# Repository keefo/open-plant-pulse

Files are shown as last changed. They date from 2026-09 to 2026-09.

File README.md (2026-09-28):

# Open Plant Pulse

Open Plant Pulse is a local-first plant monitoring system with two products:

- A battery-powered **sensor node** reads a seven-parameter NPKPHCTH-S RS485 soil
  probe and an SHT45 ambient sensor, then broadcasts each wake-cycle sample using
  BTHome v2 over BLE.
- An always-on **desktop hub** subscribes to nearby BTHome sensors on macOS or
  Linux, stores history, derives plant-state insights, and hosts a local HTTP web
  application for household management and monitoring.

The sensor can still be discovered directly by Home Assistant. The hub is for
users who want durable local history, analysis, native notifications, APIs, and
multi-system forwarding without putting those responsibilities on the battery
device.

> [!IMPORTANT]
> This repository is in the prototype stage. SQLite persistence, internal
> browser endpoints, dashboard, and BTHome encode/decode logic are tested, but
> continuous BLE collection, target hardware, predictions, and packaging have
> not been validated end to end.

## What it looks like

Small previews; click one for the whole page.

<table>
<tr>
<td width="33%" valign="top">
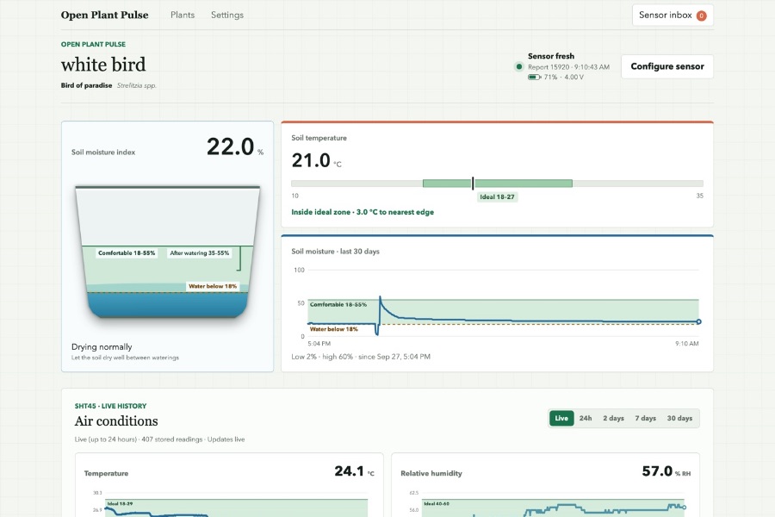
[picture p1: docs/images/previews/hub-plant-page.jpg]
A plant's page on the hub

<br><b>A plant's page</b>
<br><sub>Readings against the plant's own profile, air history, the conclusions
drawn from them, a year of care, its lights, and the log of what happened.</sub>
</td>
<td width="33%" valign="top">
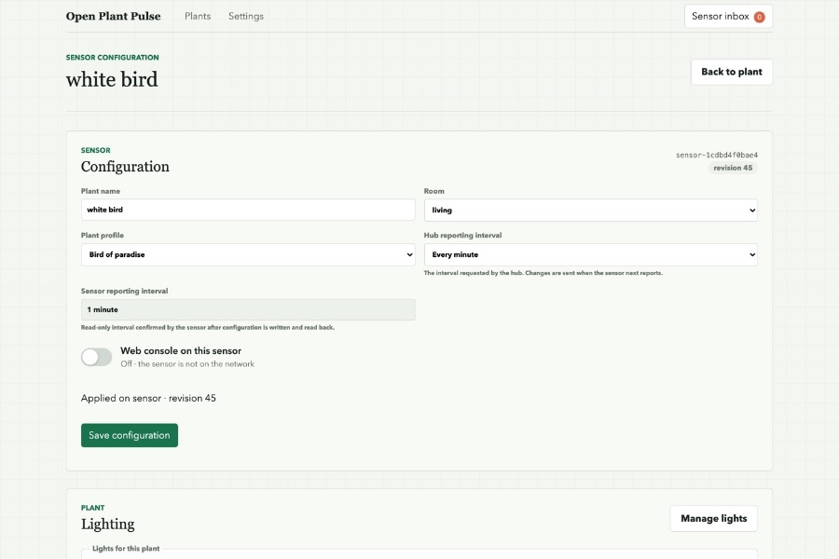
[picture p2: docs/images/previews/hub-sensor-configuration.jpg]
A sensor's configuration page

<br><b>A sensor's configuration</b>
<br><sub>What is the device's rather than the plant's: what the hub asks of it,
the lights it drives, and the firmware it runs — installed from here, over the
air.</sub>
</td>
<td width="33%" valign="top">
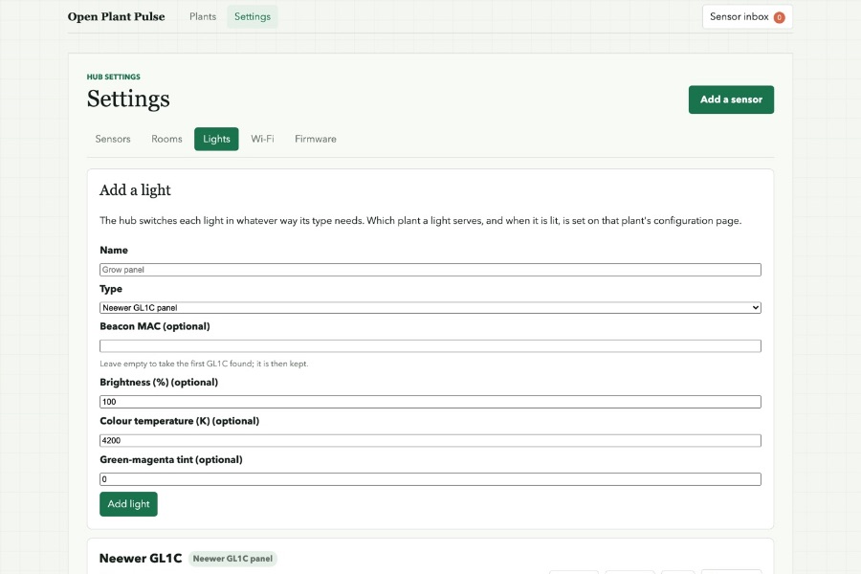
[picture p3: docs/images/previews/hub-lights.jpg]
Managing grow lights

<br><b>Grow lights</b>
<br><sub>Each light is added once and given to a plant, which owns the daily
window they follow.</sub>
</td>
</tr>
</table>

A sensor also serves its own console on the household network, for looking at
the device rather than the plant.

<table>
<tr>
<td width="50%" valign="top">
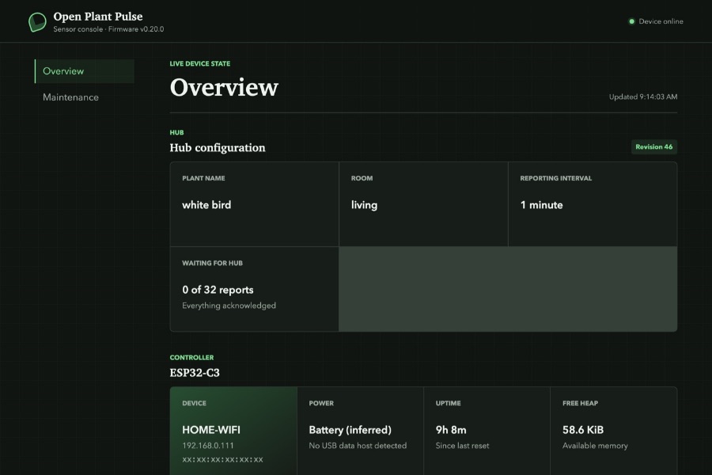
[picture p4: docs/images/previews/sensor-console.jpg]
The sensor's own console

<br><b>The sensor's console</b>
<br><sub>What each part of the device reads, what the battery is doing, and the
firmware log as it happens.</sub>
</td>
<td width="50%" valign="top">
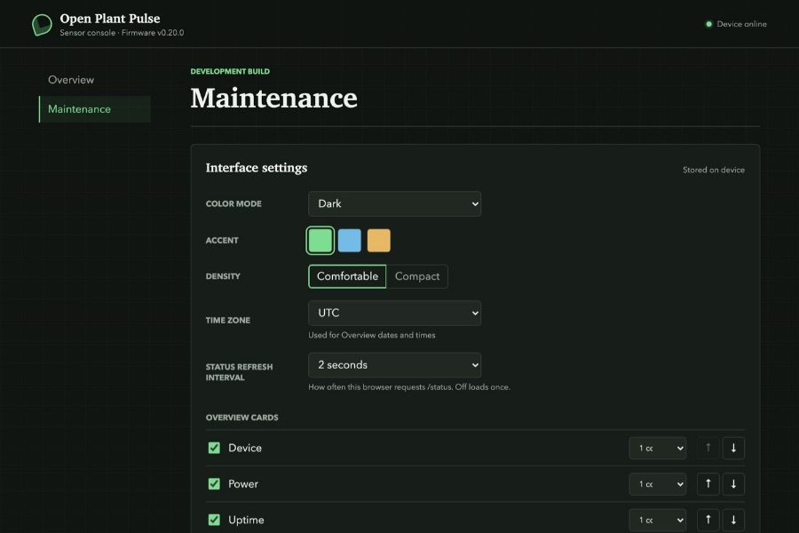
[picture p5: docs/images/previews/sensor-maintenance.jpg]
The sensor's maintenance page

<br><b>Maintenance</b>
<br><sub>Interface settings kept on the device, a forced report, and a restart.</sub>
</td>
</tr>
</table>

The Wi-Fi name and hardware addresses in these screenshots are replaced; the
readings are a real sensor's.

## Repository layout

```text
open-plant-pulse/
├── sensor/                  Battery sensor product
│   ├── firmware/            ESP-IDF application and components
│   ├── hardware/            Assembly BOM, wiring, and future CAD/PCB assets
│   └── tests/               Host-side sensor protocol tests
├── hub/                     Installable Python desktop/server product
│   ├── src/                 Domain and adapter packages
│   └── tests/               Hub unit and integration tests
├── protocol/                Versioned sensor-to-hub contract and fixtures
├── deploy/                  macOS LaunchAgent; systemd and packaging to come
├── docs/                    System architecture, setup, roadmap, and proposals
├── examples/                Downstream integration examples
└── scripts/                 Repository-wide validation commands
```

Product code stays inside `sensor/` or `hub/`. Data exchanged between them is
specified in `protocol/`; neither product may privately redefine that contract.

## Run the hub

Start the local hub from the repository root:

```sh
PYTHONPATH=hub/src python3 -m open_plant_pulse_hub
```

Open <http://localhost/>. The hub listens for BTHome advertisements from
sensors in range; add one from Settings, and its soil, air, and nutrient readings
appear as they arrive.

## Start here

1. Read [the system architecture](docs/architecture.md) and
   [shared protocol](protocol/README.md).
2. For hardware work, use the [sensor guide](sensor/hardware/README.md),
   [BOM](sensor/hardware/BOM.md), [enclosure workspace](sensor/hardware/enclosure/README.md),
   and [bring-up checklist](docs/bring-up.md).
3. To start with a XIAO ESP32-C3 and SHT45 only, follow the
   [first sensor-node guide](docs/sht45-first-node.md). For broader embedded
   development, use [the sensor firmware guide](docs/firmware.md).
4. For desktop development, follow [the hub guide](docs/hub.md).
5. Choose a direct or hub-mediated Home Assistant path in
   [the integration guide](docs/home-assistant.md).

## Repository checks

These checks require only a C compiler and Python 3.9 or newer:

```sh
sh scripts/check.sh
```

## Sensor firmware

Use the repository scripts for ESP32-C3 work. They locate and activate ESP-IDF,
select the correct project directory, and keep the commands reproducible:

```sh
sensor/firmware/build.sh
sensor/firmware/flush.sh
```

`flush.sh` builds, auto-detects a single USB serial device, flashes it, and opens
the monitor. Exit the monitor with `Ctrl-]`. Use `--no-monitor` for flash only or
`--port /dev/DEVICE` when multiple serial devices are connected. Future tooling
and automation should call these scripts instead of duplicating raw `idf.py`
commands.

## Current status

| Area | Status |
| --- | --- |
| Sensor Modbus parser and BTHome encoder | Host tested |
| Simulated sensor to hub to web dashboard | Runnable and integration tested |
| Hub SQLite persistence and current HTTP dashboard | Runnable and integration tested |
| Hub BLE subscriber and multi-sensor storage | Implemented and replay tested; macOS physical reception verified, Linux pending |
| Direct BTHome Home Assistant path | Encoder/decoder host tested; hardware pending |
| ESP-IDF target application | Firmware 0.5.0 adds a tracked manual report with exact Hub acknowledgment to the always-awake bench UI; build/flash/live results are recorded in the worklog, while production sleep/power/soak validation remains pending |
| Grow light control (Neewer GL1C, Wemo-switched light) | Running on the hub: both lights confirmed on and off, schedule edge and restart checked; GL1C colour and off edge unverified |
| Multi-plant management UI | Fleet-to-detail navigation, enrollment, per-sensor configuration delivery state, rename/delete, and sensor-specific freshness are host tested |
| Public HTTP API, sensor Wi-Fi/HTTP, MQTT, notifications | Lower priority |
| Electrical design and enclosure | Needs prototype validation |

See [the roadmap](docs/roadmap.md) for acceptance criteria. The original Chinese
[sensor](docs/proposals/sensor-node.zh-CN.md) and
[hub](docs/proposals/desktop-hub.zh-CN.md) brainstorms are retained as proposals,
not specifications. The project is licensed under the [MIT License](LICENSE).

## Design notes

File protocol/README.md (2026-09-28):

# Sensor-to-hub protocol

This directory owns the contract between the battery sensor and desktop hub.
Neither product may change its payload independently.

## BTHome contract version 3

Contract v3 is the only contract. Earlier contracts are not decoded; a sensor
still sending one is reflashed rather than accommodated. It remains unencrypted
BTHome v2 service data under UUID `0xFCD2`; `3` is the Open Plant Pulse
contract version, not a BTHome format version. Every packet begins with
device-info byte `0x40` (regular interval, unencrypted) and lists its objects in
ascending object-ID order.

One **report** is one set of measurements taken together. It always travels as
two packets that share a report ID, advertised alternately: **packet 1** with
the soil and air measurements and the acquisition time, and **packet 2** with
the battery, pH and N/P/K. Neither is optional; a report is complete only when
the hub holds both. A third shape, the **beacon**, carries no report at all.

### Packet 1: soil, air and time

Sizes include the one-byte object ID.

| Wire order | Object | ID | Encoding | Group | Size |
| --- | --- | --- | --- | --- | --- |
| 0 | Device info | `0x40` | first byte, not an object | Required | 1 |
| 1 | Soil temperature | `0x02` | signed 16-bit; factor 0.01 degrees C | Soil | 3 |
| 2 | Air relative humidity | `0x2E` | unsigned 8-bit; 1 % | Air | 2 |
| 3 | Soil moisture | `0x2F` | unsigned 8-bit; 1 % | Soil | 2 |
| 4 | Report ID (`count`) | `0x3E` | unsigned 32-bit | Required | 5 |
| 5 | Air temperature | `0x45` | signed 16-bit; factor 0.1 degrees C | Air | 3 |
| 6 | Acquisition timestamp | `0x50` | unsigned 32-bit Unix seconds | Optional | 5 |
| 7 | Conductivity | `0x56` | unsigned 16-bit; 1 microS/cm | Soil | 3 |

All multi-byte values are little-endian. A group is complete or absent: soil is
`0x02`, `0x2F` and `0x56`; air is `0x2E` and `0x45`. At least one group is
present. A failed source omits its whole group, and the receiver stores null
measurements with an unavailable source status rather than copying earlier
values. Percentages are rounded to the nearest whole point, `0` to `100`. With
everything present the service data after the UUID is 24 bytes, which with the
Flags element and service-data header fills the 31-byte legacy advertisement;
the local name travels in the scan response.

### Packet 2: battery, pH and N/P/K

| Wire order | Object | ID | Encoding | Group | Size |
| --- | --- | --- | --- | --- | --- |
| 0 | Device info | `0x40` | first byte, not an object | Required | 1 |
| 1 | Battery | `0x01` | unsigned 8-bit; 1 % | Battery | 2 |
| 2 | Battery voltage | `0x0C` | unsigned 16-bit; factor 0.001 V | Battery | 3 |
| 3 | Battery charging | `0x16` | unsigned 8-bit; `0` not charging, `1` charging | Battery | 2 |
| 4 | Report ID (`count`) | `0x3E` | unsigned 32-bit | Required | 5 |
| 5 | Soil extras (`raw`) | `0x54` | length byte `0x08`, then the layout below | Soil extras | 10 |

Battery is `0x01`, `0x0C` and `0x16` together or none of them. Charging means
current into the pack above the monitor's idle threshold (15 mA), from whatever
source: the IP2312 or the XIAO's own USB charger. Every report sends packet 2,
even when it carries only the report ID: that is how the hub knows a report is
complete, rather than guessing whether a second packet was lost or never
existed. At most 23 bytes.

BTHome defines no pH or nutrient objects, so they travel in one raw object that
only the hub decodes (Home Assistant shows battery natively and ignores it):

| Offset | Size | Field |
| --- | --- | --- |
| 0 | 1 | Layout version, `1` |
| 1 | 1 | pH, factor 0.1 (`0`-`140`) |
| 2 | 2 | Nitrogen, mg/kg |
| 4 | 2 | Phosphorus, mg/kg |
| 6 | 2 | Potassium, mg/kg |

A packet is packet 1 if it carries any of `0x02`, `0x2E`, `0x2F`, `0x45`, `0x50`
or `0x56`, and packet 2 otherwise: `0x01`, `0x0C`, `0x16` and `0x54`, or the
report ID alone. A packet mixing the two sets, missing the report ID, or carrying any
other object is malformed.

### Beacon

The single byte `0x40`, with no objects. A sensor sends it when it has no
report (for example, no sensor is available yet), so that it can still be found
and adopted. A beacon is presence only: nothing is stored from it.

### Byte budget and worked example

A legacy BLE advertisement carries at most 31 bytes. Every contract-v3 packet
spends them the same way:

```text
┌──────────────────────────── 31 bytes ────────────────────────────┐
│ 02 01 06 │ LL 16 D2 FC │ BTHome payload: up to 24 bytes           │
│  Flags   │ service-data│ 40, then objects                         │
│  3 bytes │ header, 4 B │                                          │
└──────────────────────────────────────────────────────────────────┘
```

- **Flags** (length, type `0x01`, value `0x06`) make the sensor discoverable.
- **Service-data header**: length `LL`, AD type `0x16` (service data, 16-bit
  UUID) and the BTHome UUID `0xFCD2`, little-endian `D2 FC`.
- **Payload**: 31 − 3 − 4 = **24 bytes**. It starts with the device-info byte
  `0x40`; each object is its one-byte ID followed by its little-endian value,
  in ascending ID order.

The device-info byte is a bit field defined by BTHome. `0x40` is `0100 0000`:

| Bits | Field | Value in `0x40` | Meaning |
| --- | --- | --- | --- |
| 0 | Encryption | `0` | Not encrypted |
| 1 | Reserved | `0` | |
| 2 | Trigger-based device | `0` | Advertises at regular intervals, not only on events |
| 3-4 | Reserved | `00` | |
| 5-7 | BTHome version | `010` = 2 | BTHome v2 |

Every packet 1, packet 2 and beacon begins with exactly `0x40`; any other value
is malformed. An encrypted contract would set bit 0 (`0x41`) and change the
rest of the payload, and needs a new contract.

The local name `sensor-<DEVICE_ID>` is not in this budget: it travels in the
scan response.

**Packet 1**, fixture `packet1`, 24 of 24 bytes:
`40 02 2e09 2e 2c 2f 64 3e d2040000 45 1001 50 0037b86a 56 2900`

| Bytes | ID | Value | Meaning | Size |
| --- | --- | --- | --- | --- |
| `40` | | `0100 0000` | Device info: BTHome v2, unencrypted, regular interval | 1 |
| `02 2e09` | `0x02` | 0x092E = 2350 x 0.01 | Soil temperature **23.50 C** | 3 |
| `2e 2c` | `0x2E` | 0x2C = 44 | Air humidity **44 %** | 2 |
| `2f 64` | `0x2F` | 0x64 = 100 | Soil moisture **100 %** | 2 |
| `3e d2040000` | `0x3E` | 1234 | **Report ID** | 5 |
| `45 1001` | `0x45` | 0x0110 = 272 x 0.1 | Air temperature **27.2 C** | 3 |
| `50 0037b86a` | `0x50` | 1790457600 | Timestamp **2026-09-26T21:20:00Z** | 5 |
| `56 2900` | `0x56` | 0x29 = 41 | Conductivity **41 uS/cm** | 3 |
| | | | **Total** | **24** |

**Packet 2**, fixture `packet2`, 23 of 24 bytes:
`40 01 60 0c 4010 16 00 3e d2040000 54 08 01 44 0100 0200 0700`

| Bytes | ID | Value | Meaning | Size |
| --- | --- | --- | --- | --- |
| `40` | | `0100 0000` | Device info: BTHome v2, unencrypted, regular interval | 1 |
| `01 60` | `0x01` | 0x60 = 96 | Battery **96 %** | 2 |
| `0c 4010` | `0x0C` | 0x1040 = 4160 x 0.001 | Battery **4.160 V** | 3 |
| `16 00` | `0x16` | 0 | Charging: **no** | 2 |
| `3e d2040000` | `0x3E` | 1234 | **Same report ID**, joining it to packet 1 | 5 |
| `54 08 …` | `0x54` | raw, length 8 | Soil extras, below | 10 |
| | | | **Total** | **23** |

The soil extras, `01 44 0100 0200 0700`:

| Bytes | Value | Meaning | Size |
| --- | --- | --- | --- |
| `01` | 1 | Layout version | 1 |
| `44` | 0x44 = 68 x 0.1 | pH **6.8** | 1 |
| `0100` | 1 | Nitrogen **1 mg/kg** | 2 |
| `0200` | 2 | Phosphorus **2 mg/kg** | 2 |
| `0700` | 7 | Potassium **7 mg/kg** | 2 |

**Room left** with every object present:

| Packet | Used | Free |
| --- | --- | --- |
| Packet 1 | 24 | 0 |
| Packet 2 | 23 | 1 |
| Packet 2, report ID only (`40 3e d3040000`) | 6 | 18 |
| Beacon (`40`) | 1 | 23 |

A new field must fit in the free bytes of the packet it belongs to, including
its one-byte object ID, or replace something; a third packet would spread each
report's airtime more thinly. The sensor advertises a report's two packets
alternately, swapping every 500 ms, every 50 ms while always awake and every
250 ms in the production cycle. The bulk drain does not use advertisements: its
pages travel over a connection and may be up to 512 bytes.

### Identity, report IDs and deduplication

The sensor advertises the complete local name `sensor-<DEVICE_ID>`, where
`DEVICE_ID` is its immutable 48-bit hardware device ID as 12 lowercase
hexadecimal digits. The name is the sensor's identity and stays stable across
resets, hub replacement and platform address changes. Platform-observed
addresses are diagnostics only. The identity is visible and spoofable because
the contract is unauthenticated.

Report IDs start at `1`, increase with every new report, never repeat and never
wrap. Gaps are allowed: the sensor reserves IDs in blocks in flash so that it
writes flash once per block rather than once per report, and after a restart it
continues from the end of the reserved block. `0` is never used.

The hub's key for a report is `(sensor identity, report ID)`. Packets 1 and 2
of one report may arrive in either order and are joined into one reading; a
reading appears once packet 1 is stored, with packet 2's values attached
whenever they arrive. A report is complete when
both are stored, and only a complete report is shown as a sensor's latest
reading, so one whose second packet is still coming does not blank its values. Receiving a packet whose
content matches what is already stored for its key is a duplicate and stores
nothing; this is how repeated advertising of one report is absorbed. The same
key with different content for the same packet kind is a conflict: it is
logged and not stored. Erasing the sensor's flash restarts its report IDs, so
such a sensor must be removed from the hub and adopted again.

### Security

Contract v3 is unencrypted: measurements, identity and presence are observable
and not authenticated. Encryption requires a new contract with BTHome bind-key
provisioning, protected key storage, replacement and recovery, and Home
Assistant interoperability. Keys must never appear in fixtures or logs.

### Fixtures

[`fixtures/bthome-v3.json`](fixtures/bthome-v3.json) records a known packet 1 and
packet 2 pair and a beacon. The sensor's encoder tests and the hub's
decoder tests both check against it.

### Acquisition timestamp

Use the standard BTHome timestamp object `0x50`, not a text datetime or a custom
object. Its value is a POSIX/Unix timestamp: whole seconds since
`1970-01-01T00:00:00Z`, encoded as an unsigned 32-bit little-endian integer and
interpreted in UTC. It carries no timezone offset and does not represent leap
seconds. For example, `2026-09-13T12:00:00Z` is Unix value `1789300800` and is
encoded as `50 40 90 A6 6A` including the object ID.

The Hub converts a present `0x50` value to canonical RFC 3339 UTC text in the form
`YYYY-MM-DDTHH:MM:SSZ` for its API and storage. That value becomes `observed_at`.
The separately recorded `received_at` is always the Hub's reception time and must
not be substituted for acquisition time.

The sensor emits `0x50` only after its clock has been synchronized and passes the
firmware plausibility window from `2024-01-01T00:00:00Z` through the end of 2099.
Deep sleep may retain that clock state; loss of power makes time unknown until a
new trusted synchronization succeeds. A sample acquired while time is unknown
omits `0x50` permanently, including on retries after a later synchronization. It
must not encode zero, estimate from reception time, or rewrite the immutable queued
report. The Hub stores `observed_at` as null for such a report while retaining
`received_at`; this requires a v3 storage migration because the v2 column is not
nullable.

### Durable delivery and acknowledgement

A report is kept until the hub confirms it has stored it. This replaced
one-way delivery, in which a report the hub missed was lost.

**Sensor.** Once the sensor belongs to a hub, each new report is written to a
queue in flash before it is first advertised, and stays there until
acknowledged. The sensor advertises its newest report, both packets
alternately, from the moment it is made, so the hub sees fresh data within a
second or two whatever is still queued behind it; older ones reach the hub by
the drain below. Reports are made on a fixed schedule: an advertising window is
cut short rather than delay a report that is due. A deep-sleeping sensor retries at each
wake. When the queue is full, the sensor makes no new reports and says so on its
console, rather than overwriting an unacknowledged one. An unclaimed sensor has
no hub that could acknowledge anything, so it does not queue: it advertises its
latest report without keeping it. A release by the hub clears the queue.

**Freshness.** The hub stores the newest report straight from its
advertisement, as with any packet, and shows the highest complete report ID as
the latest, so a report backfilled later never displaces a newer one.

**Hub: bulk drain.** The drain makes delivery complete and lets the sensor free
its queue. It is not the freshness path: a connection pauses the sensor's
advertising for a moment, so the hub does not drain after every report. On
hearing a report not yet acknowledged from a sensor it owns, the hub drains
when the report IDs it holds since the last acknowledgement have a gap
(something was missed over the air), when about 30 seconds have passed since
its last drain of that sensor, or on the first such report after the hub
starts. A drain that is due waits until the report just heard is complete,
both packets stored, so the connection falls in the quiet part of the
reporting cycle rather than across a fresh report; if none completes over the
air within 10 seconds it drains anyway, and other connection work waits to ride
on the same connection. Over one connection it drains the whole queue in pages, oldest first, on the
existing read/write characteristic `7f510002-1b15-4c28-9a4a-8d0f4f505000`
(bonded, encrypted):

1. Write the drain request `20`. From then on, until the end token or the
   disconnect, a read of the characteristic returns a queue page instead of
   the device configuration.
2. Read a page. Each page holds up to eight of the oldest queued reports, each
   exactly the two packets the sensor advertises for it.
3. Store every report on the page, through the same duplicate and conflict
   rules as advertised packets.
4. Write the cumulative acknowledgement for the last report stored. The sensor
   removes every queued report up to and including it.
5. Repeat from 2 until a page is empty, then write the end token `22`.

One connection moves any backlog, so draining outpaces reporting whenever the
hub is up: at a report every five seconds, a drain every 30 seconds finds about
six, two pages.
The hub does its configuration and status work on the same connection, before
the drain request or after the end token.

**Queue page** (read, at most 512 bytes):

| Offset | Size | Field |
| --- | --- | --- |
| 0 | 1 | `0x20` |
| 1 | 1 | Report count, `0` to `8` |
| 2 | ... | That many records, oldest first |

Each record is the report ID (4 bytes, unsigned little-endian), packet 1's
length (1 byte) and bytes, then packet 2's length (1
byte) and bytes: the service data exactly as advertised, after the UUID. A page
is fixed until the queue changes, so the reads that assemble a long value see
the same bytes.

**Cumulative acknowledgement** (write, five bytes):

| Offset | Size | Field |
| --- | --- | --- |
| 0 | 1 | `0x21` |
| 1 | 4 | Report ID, unsigned little-endian |

It removes every queued report with an ID up to and including this one. It is
refused, removing nothing, when the ID is `0` or beyond the last report the
sensor has put on a page during this connection: the hub can acknowledge only
what it has read. Naming a report already removed is accepted and changes
nothing. Removal is durable before the sensor answers. A report in conflict is
never acknowledged, so the hub acknowledges only up to the report before it.

**End of drain** (write, one byte): `22`. Reads return the device configuration
again; disconnecting has the same effect.

A report forced from the sensor's console is an ordinary report: it joins the
queue, and the console shows it acknowledged when a cumulative acknowledgement
covers it.

## Change policy

- There is one contract at a time. A new contract replaces the old one in the
  sensor, the hub and the fixtures together; no compatibility is kept.
- Update sensor encoding, hub decoding, replay behavior, and tests together.
- Treat incompatible identity, deduplication, encryption, or object semantics as
  a new contract version.
- Add BTHome fields in ascending object-ID order unless a documented compatibility
  reason requires otherwise.
- Document receiver behavior before emitting an object Home Assistant or the hub
  may not understand.

## Connected-BLE device configuration version 2

BTHome advertisements remain the telemetry contract. During the same bounded
advertising window, firmware also accepts a BLE connection exposing primary service
`7f510001-1b15-4c28-9a4a-8d0f4f505000` and read/write characteristic
`7f510002-1b15-4c28-9a4a-8d0f4f505000`. After an enrolled sensor advertises, the hub
writes pending device configuration and reads the characteristic back. Only an
identical read-back marks the revision applied; failures remain pending for a later
report.

The characteristic value is a canonical binary payload:

| Offset | Size | Field |
| --- | --- | --- |
| 0 | 1 | Protocol version, currently `2` |
| 1 | 4 | Non-zero configuration revision, unsigned little-endian |
| 5 | 4 | Reporting interval in seconds, unsigned little-endian, `1`–`86400`; the hub sends no less than `30` |
| 9 | 1 | Plant-name byte length, `1`–`80` |
| 10 | 1 | Room byte length, `0`–`80` |
| 11 | variable | Plant name followed by room, UTF-8 without control characters |

Version 1 used a two-byte interval in minutes and accepted only 5 minutes through
24 hours. Version 2 is intentionally incompatible so sub-minute intervals cannot be
misinterpreted by older firmware. After migration, the hub resends enrolled sensor
configuration using version 2.

The sensor validates the entire payload before atomically storing it in NVS. It
renders plant name and room on its diagnostics dashboard and uses the interval for
future awake reports or deep-sleep timer wake-ups until another valid configuration
is applied. Plant profile, thresholds, archival state, and history stay hub-owned.

This prototype characteristic is unencrypted and unauthenticated. Nearby clients
can observe or overwrite configuration. Pairing, authorization, recovery, and
measured connection-window energy are required before production deployment.

## Connected-BLE Wi-Fi credentials version 3

The hub holds one household network for the whole house and sends it to any sensor
whose web console is switched on. The sensor stores it in NVS and joins. Readings
never depend on it: telemetry is BTHome either way, and a sensor with its console
off is fully functional.

This is a third payload on the same read/write characteristic
`7f510002-1b15-4c28-9a4a-8d0f4f505000`, distinguished by its first byte as the
other two are. It is a separate payload rather than an extension of device
configuration for two reasons: that payload already occupies 171 of the roughly
253 bytes an ATT write carries at the negotiated MTU, and Wi-Fi is optional while
plant name and interval are not.

| Offset | Size | Field |
| --- | --- | --- |
| 0 | 1 | Protocol version, `3` |
| 1 | 4 | Revision, unsigned little-endian |
| 5 | 1 | Console enabled, `0` or `1` |
| 6 | 1 | Network name length, at most 32 |
| 7 | n | Network name |
| 7+n | 1 | Password length, at most 63 |
| 8+n | m | Password |

A disabled console still carries its network, so switching it back on needs
nothing resent. A payload that claims an enabled console with no network name is
refused, as is any payload whose declared lengths do not account for exactly the
bytes received. The sensor never returns the password on a read, and it appears in
no status response, log, or serial output.

> [!IMPORTANT]
> This payload carries a household secret, so it may only be written over a
> bonded, encrypted link. The characteristic requires encryption from firmware
> 0.6.0; earlier firmware accepted reads and writes from anything in range and
> must not be given credentials.

## Development transports

BLE is the only transport. Deterministic tests replay the contract-v3 fixtures
above; there is no side channel a sensor may use instead.

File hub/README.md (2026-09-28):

# Open Plant Pulse Hub

The hub is the always-on desktop/server side of Open Plant Pulse. Its target design
subscribes to BTHome advertisements over BLE, stores local history, derives
plant-state signals, and hosts a local HTTP web application where household users
manage and monitor sensors.

## Target hosts

- macOS.
- Linux.

Both hosts run the same Python BLE, HTTP, and SQLite service. Native scanning and
physical BTHome reception have been exercised on macOS; Linux permissions remain to
be tested. LAN binding and firewall behavior apply to browser access, not sensor
ingestion. Platform service packaging belongs under the repository-level `deploy/`
tree.

## Package boundaries

```text
hub/
├── src/open_plant_pulse_hub/
│   ├── domain/       Stable telemetry and plant models
│   └── ingestion/    BTHome decode, Bleak scan, replay, and development adapters
├── tests/            Hub unit and integration tests
└── pyproject.toml    Package metadata and dependency groups
```

Adapters for Bluetooth, SQLite, household HTTP, and later MQTT, notifications,
prediction, and public APIs must depend on the domain layer, not the reverse.

## Development

Run the development hub from the repository root:

```sh
PYTHONPATH=hub/src python3 -m open_plant_pulse_hub
```

Then open the fleet at <http://localhost/>. Sensor monitoring is available at
`/sensors/<sensor-id>`, where that sensor's configuration is also managed. The hub
scans for BTHome advertisements as it runs, so a sensor in range appears under
Settings and can be added from there. Readings and care events persist in SQLite;
a short live history is restored after restart.

A second server, on port 8081, serves firmware images to sensors on the household
network; the management interface above stays on loopback. Add an image under
Settings · Firmware and install it from a sensor's configuration page. Run with
`--no-firmware-server` to keep images without serving them.

The tests use only the Python standard library:

```sh
PYTHONPATH=hub/src python3 -m unittest discover -s hub/tests
```

To prepare an isolated development environment later:

```sh
python3 -m venv .venv
. .venv/bin/activate
python3 -m pip install -e './hub[dev]'
```

## Current status

The development hub receives contract-v3 BTHome advertisements through Bleak, joins
each report's packet 1 and packet 2 into one reading keyed by report ID,
drains each enrolled sensor's delivery queue over one connection (bulk drain with
cumulative acknowledgement) so the sensor can drop what the hub has stored,
persists unique readings and bounded receive
diagnostics in migrated SQLite storage, restores a short live history after
restart, serves JSON endpoints, and renders a local dashboard. The shared replay
path tests three stable sensor identities, joining in either packet order, duplicate
and conflict handling, partial sources, readings without a sensor timestamp,
malformed isolation, and adapter recovery. The production subscriber stored physical
BTHome reports on macOS, and direct CoreBluetooth access verified the firmware's
configuration write/read-back on 2026-09-14; Linux remains unvalidated.
The household UI provides a fleet page and per-sensor detail pages. Fleet cards open
the corresponding detail page and show name, stable identifier, last report, and
state. Each detail page includes all sensor configuration, archive/replacement,
destructive deletion, and pending/applied/retrying state for plant name, room, and
reporting interval. The requested hub interval remains editable while a separate
read-only field shows the interval last confirmed from firmware and used for hub
freshness calculations.
Each sensor detail page shows battery level and voltage, with a lightning bolt over
the battery while it is charging, and soil pH, nitrogen,
phosphorus, and potassium when the sensor reports them, and includes a temporary,
newest-first raw BTHome report log for debugging, capped at the latest 50 reports,
listing each packet's report ID and kind.
The sensor inbox retains deliberate enrollment.
These flows and the connected-BLE codec/read-back synchronizer are integration-tested;
single-sensor physical configuration delivery is verified, while production-hub
delivery scheduling, multi-sensor radio behavior, and responsive-browser validation
remain pending. A stable public HTTP API, sensor
Wi-Fi/HTTP, MQTT, predictive analytics, backups, and service installation are lower
priority.

The canonical current and target design is in [`../docs/hub.md`](../docs/hub.md).

## Plant profile catalog

Plant profiles are JSON data under
`src/open_plant_pulse_hub/data/plant_profiles/`. Add one file following the
directory README and schema; the generic loader discovers and validates it
without any Python registry change.

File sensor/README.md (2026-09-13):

# Open Plant Pulse sensor

The sensor is the battery-powered product installed at the plant. It reads a
ComWinTop NPKPHCTH-S soil probe over Modbus RTU and an SHT45 air sensor over I2C,
encodes implemented measurements as BTHome v2, briefly advertises over BLE, and
returns to deep sleep. The probe supports N/P/K, pH, conductivity, soil
temperature, and soil moisture; firmware currently implements only the latter
three.

```text
sensor/
├── firmware/          ESP-IDF main component and reusable protocol components
├── hardware/          Top-level assembly BOM and hardware guidance
├── tests/             Dependency-free C protocol tests
├── CMakeLists.txt      ESP-IDF project entry point
└── sdkconfig.defaults Portable target defaults
```

Read the [firmware guide](../docs/firmware.md),
[hardware guide](hardware/README.md), and
[enclosure workspace](hardware/enclosure/README.md), and
[shared radio contract](../protocol/README.md) before making changes.

From the repository root, use the canonical scripts:

```sh
sensor/firmware/build.sh
sensor/firmware/flush.sh
```

The flash script builds first, auto-detects a single USB serial port, flashes,
and opens the monitor. Run `sensor/firmware/flush.sh --help` for explicit port
and flash-only options. Reuse these scripts in development and automation rather
than assembling separate `idf.py` command sequences.

Run sensor protocol tests from the repository root:

```sh
sh scripts/test-sensor.sh
```

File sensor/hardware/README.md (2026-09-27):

# Hardware

The procurement source of truth is the [bill of materials](BOM.md) and its
machine-readable [`bom.csv`](bom.csv). The table below summarizes the prototype
architecture and must not be used as a substitute for exact orderable parts.

## Reference prototype

| Function | Reference part | Required verification |
| --- | --- | --- |
| Controller | Seeed Studio XIAO ESP32-C3 | Board revision and pin map |
| RS485/power | XIAO-format RS485 expansion board | Input range, 12 V capacity, enable pin, idle current |
| Probe | ComWinTop NPKPHCTH-S | Product revision, wire colors, voltage, register map, scaling |
| Air sensor | Sensirion SHT45 or SHT45 breakout | Exact MPN/module, supply voltage, mounting, idle current |
| Battery | Protected 3.7 V 18650 cell and holder | Protection, polarity, peak-current capability |
| Cable entry | PG7 gland sized for probe cable | Grip and ingress protection |
| Enclosure | Printed PETG/ASA prototype | Clearances, ventilation, strain relief |

Part numbers are not interchangeable merely because they share an enclosure or
product-family name. Save each purchased part's manual and revision under a
release or issue before freezing the design.

## Pin map

This is the assembled prototype's wiring: a XIAO ESP32-C3 on the XIAO RS485
board, with the SHT45 and INA219 sharing one I2C bus.

| Signal | XIAO label | ESP32-C3 GPIO | Connected to |
| --- | --- | --- | --- |
| RS485 UART TX | D4 | GPIO6 | RS485 board transceiver input |
| RS485 UART RX | D5 | GPIO7 | RS485 board transceiver output |
| RS485 driver enable | D2 | GPIO4 | RS485 board DE |
| I2C SDA | D1 | GPIO3 | SHT45 and INA219 SDA |
| I2C SCL | D3 | GPIO5 | SHT45 and INA219 SCL |
| Probe power | D10 | GPIO10 | AO3400 gate: high powers the MT3608 and probe |

The RS485 board occupies D4/D5, so no I2C device may use them: the
transceiver's receiver output actively drives D5, which corrupts I2C. The
ESP32-C3 has one I2C controller, so every I2C device belongs on D1/D3. The
INA219 at `0x40` and the SHT45 at `0x44` do not collide; do not bridge the
INA219's A1 pad, which would move it to `0x44`.

The probe is powered from an MT3608 boost converter set to 12.4 V on the system
node, switched by an AO3400 N-MOSFET in the MT3608's ground (see
[probe power switch](#probe-power-switch)).

## Power path

The assembled prototype runs from two 18650 cells in parallel (still one 3.7 V
cell electrically) and charges them through an IP2312 USB-C charger module.

| From | To | Notes |
| --- | --- | --- |
| USB-C charger | IP2312 USB-C input | The only charging input |
| IP2312 BAT+ | System node | Short, thick wires (20-22 AWG) |
| System node | INA219 VIN+ | |
| INA219 VIN- | Battery pack P+ | The shunt sits in series with the pack |
| System node | MT3608 IN+ | Boost converter for the probe |
| System node | XIAO BAT+ pad | Powers the controller |
| MT3608 OUT+ (12.4 V) | Probe brown | Set the voltage before connecting the probe |
| MT3608 OUT- | Probe black | Same net as MT3608 IN-, switched by the AO3400 |
| MT3608 IN- | AO3400 drain (pin 3) | The MT3608's only path to ground |
| AO3400 source (pin 2) | System ground | |
| XIAO D10 (GPIO10) | AO3400 gate (pin 1) | 10-100 kOhm gate-to-source pull-down |

IP2312 BAT-, pack P- and the XIAO BAT- pad share one ground. MT3608 IN- and
OUT- reach it only through the AO3400. The
INA219 and SHT45 take ground from the XIAO GND pin, which is the same net.

Because the INA219's VIN+ is on the system node and VIN- on the pack, its
current is **positive while charging** and negative while the node runs from
the battery. The firmware reads it as a battery monitor; see
[firmware development](../../docs/firmware.md#battery-monitor). Its shunt value
and the cells' capacity are build settings that must match the parts.

### Probe power switch

The MT3608's own enable pin cannot switch the probe off: a disabled boost
converter still passes the battery voltage, less a diode drop, through its
inductor and diode to the output, leaving the probe half powered. None of the
other modules can switch a load either, and the RS485 board's 12V terminal is
an input to its 12 V to 5 V regulator, not an output.

An AO3400 N-MOSFET (SOT-23; 30 V, 5.7 A, fully on at 3.3 V gate) therefore
switches the MT3608's ground, which takes the MT3608 and the probe together:

- Pin 3 (drain, the lone pin) to MT3608 IN-; pin 2 (source) to system ground;
  pin 1 (gate) to D10, with 10-100 kOhm from gate to source so the probe stays
  off through reset. With the marking readable and the lone pin at the top,
  pin 1 is bottom left and pin 2 bottom right. In diode mode only source (red)
  to drain (black) conducts, at about 0.6 V.
- MT3608 IN- must have no other path to ground, or the switch is bypassed.
- Do not switch the probe's black wire alone: the MT3608 would keep 12.4 V on
  brown and the probe would try to power itself through A/B.
- When on, the RS485 ground reference passes through the MOSFET, a few
  millivolts of offset, well within RS485's common-mode range. When off, the
  probe's ground floats.

Measured 2026-09-26 on battery (USB unplugged), 30 s averages: probe on
-98.0 and -98.1 mA, off -69.5 mA. **The MT3608 and probe cost 28.5 mA**, about
120 mW at 4.17 V. The probe answers within 2.1 s of power-on, and moisture,
temperature and conductivity are right on the first read. pH is not: 3.3 on
the first read, 5.6 ten seconds later, 6.0-6.8 after long operation. A
short power-up per reading will need a longer warm-up, or flagged pH.

While USB is connected the INA219 cannot show this. Near full, the charger
holds the system node at 4.2 V and supplies the loads directly; the pack
current then depends only on the pack voltage, so switching a load changes
the charger's current, not the INA219's. Measure loads on battery alone.

### The node must have its battery in

With no battery fitted, the only source on the system node is the XIAO's own
small Li-ion charger, fed from the XIAO's USB port. It is sized to top up a
cell, not to run a load, and cannot supply the MT3608 and the probe (up to
0.5 W). The probe's supply then sags. Its main controller keeps running, so it
still answers Modbus and reports conductivity, but its moisture/temperature
sensor and pH electrode do not start, and it reports those as exactly `0`.
Observed 2026-09-26: moisture 0 %, temperature 0.0 C and pH 0 with EC 169
uS/cm in water on USB alone; 77.6 %, 25.7 C and pH 4.8 as soon as the battery
was fitted. Bench-test anything involving the probe with the battery in.

The XIAO's charger also charges the pack whenever the XIAO's USB is connected,
so avoid charging through the IP2312 at the same time.

## Probe wiring

From the CWT "NPK type" manual V1.4, which applies to the five-needle
NPKPHCTH-S:

| Probe conductor | Function | Connected to |
| --- | --- | --- |
| Brown | Power + (DC 4.5-30 V) | MT3608 OUT+ (12.4 V) |
| Black | Power - | MT3608 OUT- / common ground |
| Yellow or green | RS485 A+ | RS485 board A |
| Blue | RS485 B- | RS485 board B |

Reversed A/B is usually non-destructive but prevents communication; reversed
power may permanently damage the probe.

RS485 board settings: A and B terminals to the probe; the 5V, 12V, GND and INT
terminals unused; the 5V IN/OUT switch at IN; the 120R termination switch ON.
The A/B terminals are the RS485 bus side of the board's transceiver. D4, D5 and
D2 reach the transceiver's logic side through the board itself when the XIAO
is plugged in.

Replies occasionally arrive a byte or more short, or with the last bits
flipped (for example a CRC of `ef d5` where `ef 15` was due). The firmware
retries a failed read up to three times, which has recovered every sample so
far. Most of these were seen while the node ran on USB alone, so they may share
that cause; if they persist with the battery in, try the 120R switch OFF, since
a 2 m cable at 4800 baud needs no termination.

## NPKPHCTH-S soil probe

The selected `NPKPHCTH-S` is a multi-parameter insertion probe that exposes
seven advertised soil measurements through RS485 using Modbus RTU:

| Measurement | Typical unit | Project use |
| --- | --- | --- |
| Nitrogen (N) | mg/kg | Nutrient trend; not yet implemented |
| Phosphorus (P) | mg/kg | Nutrient trend; not yet implemented |
| Potassium (K) | mg/kg | Nutrient trend; not yet implemented |
| pH | pH | Acidity/alkalinity trend; not yet implemented |
| Electrical conductivity | microS/cm | Dissolved-ion/salinity trend; contract v1 |
| Soil temperature | degrees C | Root-zone temperature; contract v1 |
| Soil moisture | % | Root-zone water trend; contract v1 |

The probe is intended for continuous in-soil measurements with corrosion-resistant
316 stainless-steel electrodes and an IP68-style sealed body. Those construction
and ingress claims must be confirmed against the purchased revision's datasheet.

NPK and pH readings from a compact in-soil probe are best treated as trends until
compared with appropriate reference methods. They do not replace laboratory soil
analysis. Before enabling any field, verify the purchased unit's supply voltage,
Modbus address, baud/parity, register address, signedness, scaling, valid range,
warm-up time, and CRC behavior from its exact manual and bench measurements.

Firmware reads all seven registers (`0x0000`-`0x0006`, address 1, 4800 baud
8N1) per the manual, and all seven are broadcast to the hub in contract v3. See [firmware development](../../docs/firmware.md#soil-probe).

### Observed register map

A raw dump of the purchased probe (address 1, 4800 baud, needles in tap water,
battery fitted) matches the manual throughout:

| Register | Meaning | Raw | Scaled |
| --- | --- | --- | --- |
| `0x0000` | Moisture | 776 | 77.6 % |
| `0x0001` | Temperature | 257 | 25.7 C |
| `0x0002` | Conductivity | 166 | 166 uS/cm |
| `0x0003` | pH | 48 | 4.8 |
| `0x0004`-`0x0006` | N, P, K | 7, 11, 27 | mg/kg |
| `0x0007` | Salinity | 91 | 0.55 x conductivity |
| `0x0008` | TDS | 83 | 0.50 x conductivity |
| `0x0023`, `0x0024` | Salinity, TDS factors | 55, 50 | Manual defaults |
| `0x07D0`, `0x07D1` | Slave ID, baud code | 1, 1 | Address 1, 4800 baud |

With the needles fully submerged in a second glass of tap water, the probe
settled within about 30 s at moisture 100.0 % (raw 1000), temperature 25.7 C
(air 27.2 C), conductivity 97 uS/cm, pH 4.5, N/P/K 3/6/16, salinity 53 and TDS
48. That container was not clean: in a clean container of the same tap water
the probe settled at moisture 100.0 %, temperature 23.8 C (air 26.7 C),
conductivity 41 uS/cm, pH 6.8 (drifting down from 7.4 over two minutes) and
N/P/K 1/2/7. The residue had raised conductivity and made the water acidic,
and the probe measured both correctly. Rinse the container before any water
test.

In air, with needles wet from the water, moisture read about 4 % and then
0.0 %, conductivity and N/P/K 0, and temperature about 3 C below the air while
the wet probe cooled by evaporation. pH wandered between 3.0 and 8.2: a pH
electrode needs liquid contact, so pH in air is noise. A starved probe (see
[above](#the-node-must-have-its-battery-in)) is different: its temperature
reads exactly 0.0.

N, P and K move with conductivity (7/11/27 at 166 uS/cm, 3/6/16 at 97 uS/cm,
1/2/7 at 41 uS/cm):
they are estimates derived from it, not independent measurements. The probe answers both function `0x03` and `0x04`.
The firmware's seven-register `0x03` read is reliable; a sixteen-register
`0x03` read once returned zeros where `0x04` returned the values, so use
`0x04` when dumping wider ranges. pH settles slowly, over minutes; check it
against a buffer solution before relying on it, and see the offset register
`0x0053`.

## SHT45 air sensor

The SHT45 adds ambient air temperature and relative humidity at its default I2C
address `0x44`. These measurements are distinct from the RS485 probe's soil
temperature and soil moisture.

- Select a **standard 2.54 mm (0.1 in) pin-header solder-pad breakout** with
	castellated-edge or through-hole header termination, then record its exact MPN.
	Bare sensors and breakout boards have different power, pull-up, and mounting
	requirements.
- Mount the sensing opening in ventilated ambient air, outside any sealed
	electronics volume.
- Isolate it from heat produced by the ESP32-C3, boost converter, battery, direct
	sunlight, and warm walls to avoid biased air-temperature readings.
- Prevent liquid water, soil, and conformal coating from reaching the sensing
	opening. A ventilated protective cap is not an independently verified IP rating.
- Confirm whether I2C pull-ups are present before adding another set.
- Measure sleep and active current as part of the complete sensor-node budget.

A broken SDA or SCL joint does not always stop the SHT45 from acknowledging its
address. On 2026-09-26 it was found at `0x44` but every measurement failed its
CRC until a broken wire was repaired, so repeated CRC failures point at wiring
first. Heat from the soldering iron or nearby electronics also shows up
directly: 35 C just after rework, settling to 27.6 C.

## Power and battery safety

See [sensor power management](../../docs/power-management.md) for the intended
always-on and switched rails, RTC wake path, SHT45 standby choices, RS485 probe
shutdown requirements, and complete-system current budget.

- Use only a qualified, protected single-cell Li-ion battery in a holder.
- Verify polarity and absence of shorts with a meter before inserting the cell.
- Confirm that USB charging and load sharing are supported for the board revision.
- Measure boost-converter startup current and battery voltage sag under load.
- Fuse the prototype during bench bring-up and keep it away from soil and water.
- Do not claim an IP rating for a printed enclosure without a tested sealing plan.

The XIAO documentation lists approximately 44 microA for the board in deep
sleep, before expansion-board, regulator, and battery-protection losses. The
brainstorm's sub-20-microamp system target is therefore not a validated baseline.

## Artifact layout

Add source artifacts only when they exist:

```text
sensor/hardware/
├── bom.csv         Canonical top-level assembly BOM
├── BOM.md          BOM schema and maintenance policy
├── electronics/    KiCad schematic, PCB, libraries, and fabrication outputs
├── enclosure/      Editable CAD, STEP/STL exports, drawings, and print notes
└── datasheets/      Redistribution-permitted manuals or links/index files
```

See the [enclosure workspace](enclosure/README.md) for its model/export layout.
Generated fabrication files should identify their source revision and release.

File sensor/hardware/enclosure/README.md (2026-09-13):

# Sensor enclosure

This directory owns the mechanical design for the sensor electronics housing.
Commit both the editable model and practical exports so contributors can modify
the design without preventing builders from printing it.

## Layout

```text
enclosure/
├── source/       Editable native CAD files and linked design parameters
├── step/         Neutral STEP exports for interchange and fit checks
├── stl/          Print-ready STL meshes, one oriented part per file
├── drawings/     Dimensioned PDF/DXF drawings and assembly diagrams
└── README.md     Design status, export metadata, and print instructions
```

The native model in `source/` is the source of truth. STEP, STL, PDF, and DXF
files are generated release artifacts, but they are intentionally versioned so
builders do not need the original CAD application.

## File conventions

- Design in millimetres and model parts at 1:1 scale.
- Use descriptive lowercase names, for example `controller-housing-v1.step` and
  `controller-housing-lid-v1.stl`.
- Keep separate printable parts in separate STL files.
- Include the design revision in every exported filename.
- Record the CAD application/version, source commit, export date, material,
  orientation, supports, layer height, wall count, and tolerances below.
- Do not commit slicer-generated G-code; it is printer- and material-specific.
- Do not claim water resistance or an IP rating without documented testing.

## Current design

Status: unprinted sensor-node prototype. The first design holds the Seeed RS-485
Breakout Board for XIAO, a stacked XIAO ESP32-C3, the SHT45 breakout, and a
ready-made dual-18650 holder. It does not include the final probe cable
gland.

| Property | Value |
| --- | --- |
| CAD tool and version | Blender 4.5; parametric Python source |
| Design revision | `air-node-case-v1` |
| Intended material | PETG prototype |
| Nozzle / layer height | 0.4 mm / 0.2 mm candidate |
| Required supports | None in exported orientation |
| Source commit used for exports | TBD |
| Fit-test result | Not tested |

### Air-node prototype

The editable generator is `source/air-node-case-v1.py`; running it through
Blender creates `source/air-node-case-v1.blend` and separate base/lid STL files.
All dimensions are in millimetres and the important clearances are constants at
the top of the script.

| Dimension | Value |
| --- | --- |
| XIAO ESP32-C3 footprint | 21.0 x 17.8 mm |
| SHT45 breakout footprint | 13.29 x 10.26 mm |
| Board-edge separation | 15.0 mm |
| Seeed RS-485 carrier | 42 x 25 x 14 mm published envelope |
| Provisional RS-485 plus XIAO height | 18 mm |
| RS-485 mounting bases | Four 6.5 mm OD x 3.0 mm high standoffs |
| RS-485 mounting pilots | 2.7 mm blind M3 thread-forming holes |
| Provisional RS-485 hole pattern | 2.0 mm from side edges; rows 23 and 39 mm from USB end |
| Dual-18650 holder envelope | 77.0 x 39.5 x 18.3 mm |
| Battery-holder pocket | 77.8 x 40.3 mm; 0.4 mm clearance per side |
| Electronics compartment width | 35.0 mm; 3.0 mm service space outside each RS-485 rail |
| Nominal outside size | 83.8 x 83.3 x 27.0 mm |
| Wall / floor / lid | 3.0 / 2.0 / 2.8 mm |
| Per-side board clearance | 0.4 mm |
| USB-C opening | 11.5 x 6.5 mm prototype clearance, elevated for stack |
| USB-C position | Approximately 0.15 mm inside outer wall; stack shifted 1.4 mm toward USB opening |
| External probe-cable opening | 5.8 mm circular pass-through for measured 5.0 mm NPKPHCTH-S cable |
| SHT45 side opening | 5.0 x 5.0 mm rounded aperture |
| SHT45 fastener | 3.4 mm M3 clearance with 6.4 mm head recess |
| Antenna cable pass-through | 4.0 x 3.2 mm rounded slot |
| Internal antenna cable guide | 2.2 mm channel for nominal 1.13 mm coax |
| Antenna location | Outside USB end wall, on the battery-side portion |
| Battery isolation wall | 2.0 mm full-length partition, 2.8 mm sliding-lid clearance |
| Battery-lead pass-through | 8.0 x 5.0 mm rounded opening near the XIAO |
| Lid retention | 1.2 mm captured tongues and upper rails in 2.0 mm-high grooves |
| Lid running clearance | 0.4 mm nominal in XY and Z, with a recessed 14 mm thumb notch |

The RS-485 carrier uses four M3 mounting bases plus side rails. Its hole pattern
is estimated from the supplied product photograph because dimensioned mounting
data is not available. Measure all four hole centers on the physical board and
update the generator constants before printing. The SHT45 mounts vertically on
the right end wall with its sensing corner facing a 5 mm opening. One M3 screw
clamps the board while three edge rails prevent rotation. The sensor and M3
offsets are estimated from the supplied photograph and must be measured before
printing. The USB-C opening, terminal-block cable slot, assembled stack height,
RS-485 mounting holes, and sliding-lid fit must also be checked when the
physical board arrives. The SHT45 opening prioritizes airflow and is not
splash-proof or IP rated.

The ready-made dual-18650 holder occupies a simple rectangular bay behind the
2 mm partition. The compartment walls locate its measured 77.0 x 39.5 mm
footprint with 0.4 mm clearance per side; the former cell cradles and end-stop
ridges are removed. The Blender reference includes the holder floor, side rails,
center spine, terminal walls, contacts, and coil springs. Only the outer envelope
is measured; verify the internal details against the physical holder. The battery harness crosses through a localized rounded
opening in the partition near the XIAO; add edge protection where the lead
crosses the wall. The separate outer-wall slot is for the external soil probe
cable, not the battery. Replace that provisional slot with a measured
cable-gland hole in the final design. Verify whether the purchased holder wires
its cells in series or parallel and add suitable pack-level protection before
connecting it. Use matched cells at the same state of charge, and measure the
holder, contacts, leads, and connector before printing.

The screwless lid slides in from the USB end and finishes flush with the top of
the rounded shell. Stepped tongues on both long edges run beneath retaining lips,
and the uncut far end wall provides the insertion stop. The 2.8 mm panel embeds
the tongues within its thickness so both broad faces are planar. A semicircular
thumb notch at the entry edge allows removal without an external tab. The four
former lid M3 bosses and matching lid holes are removed; the four RS-485 board
standoffs remain. The lid STL is oriented with its broad outer face on the build
plate so the rail tongues expand laterally in the upper layers without support.
Print a short rail-fit coupon before the full enclosure and adjust the nominal
0.4 mm clearance for the selected material and printer.

The first fit test places the adhesive BLE antenna outside on the USB end wall,
using the battery-side portion so it does not obstruct USB-C. Feed the U.FL plug
inward through the electronics-side antenna slot before connecting it to the
XIAO, then lay the coax between the guide rails without a sharp bend or tension
at the connector. This position places the cells behind the antenna, so compare
BLE range with the previous electronics-side long-wall position before fixing
the final location. The modeled 45 x 20 mm antenna paddle is a visual
placeholder; measure the supplied antenna before adding retention features.
Sealant or a grommet may be added after fit testing, but the current slot is not
water-resistant.

## Design requirements

- Retain the XIAO ESP32-C3 and RS485 board without stressing headers.
- Provide protected-cell retention and safe battery removal.
- Provide strain relief sized to the measured probe cable and gland.
- Keep conductive parts and the battery isolated from condensation.
- Place the SHT45 in ventilated ambient air with a protective opening that does
  not trap condensation or expose it to direct splashes.
- Thermally isolate the SHT45 from the controller, boost converter, battery, and
  sun-heated enclosure surfaces.
- Preserve external BLE antenna clearance and orientation.
- Allow access to USB-C, reset/boot recovery, and service fasteners.
- Avoid trapped water and document the installed orientation.

Update this document when the first source model is added. A hardware release
must export matching STEP and STL files from the tagged source revision and
record its fit and print validation in the bring-up report.

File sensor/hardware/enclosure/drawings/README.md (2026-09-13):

# Drawings

Store revisioned dimensioned drawings, assembly diagrams, and PDF/DXF exports
here. Drawings must state units and correspond to the same source-model revision.

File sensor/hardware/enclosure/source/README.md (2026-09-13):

# Editable CAD source

Store the native, editable parametric model and any project-local parameter files
here. This directory is the mechanical source of truth; identify the CAD tool and
version in the parent [enclosure documentation](../README.md).

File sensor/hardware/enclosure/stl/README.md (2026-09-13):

# Printable STL files

Store revisioned, print-ready `.stl` meshes here. Export one oriented physical
part per file and record print settings in the parent enclosure documentation.
Do not store printer-specific G-code.

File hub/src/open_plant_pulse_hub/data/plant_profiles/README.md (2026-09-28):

# Plant profiles

Plant knowledge is data, not Python code. Each public profile lives in its own
JSON file so a contribution can add or improve one plant without modifying the
hub loader.

## Add a profile

1. Copy the closest existing profile to `<profile_id>.json`.
2. Set `id` to the filename without `.json`; use lowercase letters, numbers,
   and underscores.
3. Keep `schema_version` at `1` and retain the `$schema` reference for editor
   validation.
4. Supply sources and reasoning in the pull request. Profile values are broad
   starter guidance, not laboratory or fertilization instructions.
5. Run `sh scripts/check.sh`. The loader discovers the file automatically; no
   Python registry edit is required.

`_catalog.json` contains catalog-wide display guidance, the default profile,
and whole-plant status levels. Files beginning with `_` are metadata and are
not loaded as plant profiles.

## Watering fields

- `refill_below`: point where watering becomes appropriate.
- `post_water_target`: desired range immediately after watering.
- `comfortable_cycle`: normal wet-to-dry movement between waterings.
- `concern_below` / `concern_above`: outer safety limits.

Thresholds use the sensor's calibrated 0–100 moisture index, not volumetric
water content. Pot, substrate, placement, and individual plant history can
require instance-specific adjustments in a future plant registry.

## Chemistry fields

- `root_zone.conductivity_us_cm.ideal`: target **pore-water** EC in µS/cm, the
  conductivity of the soil water itself as a drainage or pour-through test
  measures it. The probe measures bulk EC, which reads far lower in an airy mix,
  so the hub holds this range against its pore-water estimate and reports the
  result as the nutrient level. Take values from pore-water or pour-through
  guidance, not from bulk soil-probe figures.
- `chemistry.*`: pH and nitrogen/phosphorus/potassium ranges are kept as reference
  data. The page shows the probe's pH as unverified and its N/P/K, which the probe
  derives from EC, as trend-only estimates, and judges neither against these ranges.

## Drainage fields

- `preferred_response`: ideal learned pot response: `fast`, `balanced`, or
   `retaining`.
- `acceptable_responses`: response classes considered suitable for the plant.
- `maximum_settle_minutes`: longest desired post-watering stabilization time.
- `label`: concise human-readable substrate and drainage guidance.

The hub learns response from the moisture peak and stable plateau after
watering. This measures retention and redistribution near the probe, not water
leaving a drainage hole. Suitability remains in a learning state until at least
three completed watering cycles are available.

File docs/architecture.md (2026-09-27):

# System architecture

## Context

```mermaid
flowchart LR
    Probe[RS485 soil probe] --> Sensor[Battery sensor node]
    Air[SHT45 air temperature / humidity] --> Sensor
    Sensor -->|BTHome advertisements: newest report| Subscriber[Hub BLE subscriber]
    Subscriber -->|Connected BLE: configuration, bulk drain, acknowledgement| Sensor
    Subscriber --> Hub[Hub application]
    Hub --> DB[(SQLite)]
    User[Household user] <-->|HTTP browser UI| Hub
    Sensor -.->|same advertisements| HA[Home Assistant]
    Hub -.->|later MQTT| HA
    Hub -.->|later public HTTP API| Clients[External clients]
```

The sensor owns physical sampling, Modbus decoding, SHT45 I2C communication,
measurement validation, BLE advertising, and deep sleep. The hub listens for
normalized BTHome advertisements; it does not parse Modbus frames or SHT45
commands.

The hub has two first-class runtime functions: continuous BLE ingestion and a
local HTTP server for household management and monitoring. The browser server is
not the sensor transport. A stable external HTTP API and sensor Wi-Fi/HTTP
reporting are deferred until the BLE path works and measured requirements justify
them.

## Product boundaries

| Boundary | Owns | Must not own |
| --- | --- | --- |
| `sensor/` | Probe power, UART/Modbus, SHT45/I2C, scaling, BTHome advertising, sleep | History, users, analytics, downstream integrations |
| `hub/` | BLE subscription, enrollment, identity mapping, persistence, web UI, analytics, later APIs/notifications | Probe wiring or register-map assumptions |
| `protocol/` | BTHome objects, identity/deduplication semantics, units, fixtures, version policy | Platform Bluetooth or storage code |
| `deploy/` | Service definitions, Bluetooth permissions, installation, upgrades | Domain logic |

## Sensor lifecycle

The node wakes on an RTC timer, samples the SHT45, powers the soil probe, waits
for stabilization, validates Modbus registers, removes probe power, advertises a
bounded BTHome burst, stops the radio, and returns to deep sleep. A failure must
still remove probe power and sleep. An unavailable hub cannot extend the sensor's
awake period: the advertisement does not wait for anyone, and reports the hub
has not yet stored stay in the sensor's queue for a later wake.

Reports are advertised one-way, but delivery is confirmed: a sensor that
belongs to a hub keeps each report in a queue in flash until the hub, over a
connection, reads and acknowledges it (see
[how a report reaches the hub page](#how-a-report-reaches-the-hub-page)). A
separate part of the same connected-BLE service sends plant name, room, and
reporting interval when an enrolled sensor next advertises.
The sensor validates and stores those fields in NVS, reads them back as an
acknowledgement, and uses the interval for subsequent reports. Profiles, thresholds,
history, and archival state remain hub-owned.

See [sensor power management](power-management.md) for the RTC wake mechanism,
power domains, failure-safe cleanup, and current-budget method.

## Hub architecture

The hub follows dependency direction toward a platform-independent domain:

```mermaid
flowchart LR
    Bleak[Bleak subscriber] --> Ingest[Ingestion service]
    Replay[BLE fixture replay] --> Ingest
    Ingest --> Domain[Domain models and rules]
    Ingest --> Repo[Repository interface]
    SQLite[SQLite adapter] --> Repo
    Web[Household HTTP and web adapter] --> Domain
    MQTT[Later MQTT adapter] --> Domain
    PublicAPI[Later public API] --> Domain
```

- **Domain:** telemetry, plants, thresholds, freshness, and derived results.
- **Application:** enrollment, ingestion, deduplication, retention, and care flows.
- **Adapters:** Bleak, fixture replay, SQLite, household HTTP,
  and later MQTT, public APIs, and OS notifications.
- **Client:** the first client is the hub-hosted household web application.

Bluetooth collection, storage, and HTTP serving share one service but have
independent failure handling. A browser, MQTT broker, or future API client must
not block BLE ingestion. A Bluetooth outage must not make stored history
unavailable through the browser.

SQLite is the first durable source of truth. Another analytical database may be
used only as a later export or offline tool.

## How a report reaches the hub page

```mermaid
flowchart LR
    subgraph Sensor[Sensor, XIAO ESP32-C3]
        Samples[Sensors sampled\nevery few seconds] --> Page1[Sensor web page\nlive samples]
        Samples -->|every reporting interval| Queue[(Report queue\nin flash, 32)]
        Queue -->|newest report| Adv[Advertising\npacket 1 / packet 2]
    end
    Adv -->|over the air, ~1 s| Store[(Hub database)]
    Hub[Hub] -->|drain: read pages,\nacknowledge up to N| Queue
    Hub --> Store
    Store -->|highest complete report| Page2[Hub page\npolls every 1 s]
```

Two paths carry a report, and they do different jobs:

- **Freshness: advertising.** Every reporting interval the sensor turns its
  latest samples into a report, writes it to the queue, and advertises that
  newest report straight away as two packets, alternately. The hub stores both
  from the air and shows the highest complete report as the latest. Measured at
  a 5-second interval: page updates median 5.0 s apart, 2 to 3 s behind the
  sensor's own page.
- **Completeness: the bulk drain.** Over the air the hub misses some packets. So
  it also connects and reads the sensor's queue in pages of up to eight reports,
  stores whatever it lacked, and acknowledges "up to report N"; the sensor then
  deletes those. It drains on a gap in report IDs, every 30 seconds, and on the
  first report after a restart, and waits until the report it just heard is
  complete, because a connection briefly pauses advertising. One connection
  clears any backlog in about a second.

Where things live, and what follows from it:

| Thing | Where | So |
| --- | --- | --- |
| Live samples | Sensor RAM | The sensor's own page is always current |
| Report queue | Sensor flash (NVS), up to 32 reports | Nothing is lost while the hub is down, restarting or out of range: 16 minutes at a 30-second interval, 16 hours at 30 minutes |
| History | Hub SQLite | The hub page shows only what has arrived |
| Latest reading | Hub, highest complete report ID | A report filled in later by a drain never replaces a newer one |

- **The two pages can differ for a moment.** The sensor page shows samples; the
  hub page shows the last complete report. At a 5-second interval the gap is
  normally 2 to 3 s; a report missed over the air shows up only when the next
  drain fills it in, and the page skips ahead meanwhile.
- **If the hub is down,** the queue fills at one report per interval. At 32
  the sensor stops making new reports rather than overwrite one, and its Hub
  section says so; when the hub returns, the first drain empties it.
- **Report IDs** only increase and never repeat. They are reserved in blocks of
  100 in flash, so a restart leaves a gap, which is harmless. Erasing the
  sensor's flash restarts them, and the sensor must then be removed from the
  hub and adopted again.
- **Unclaimed sensors** have no hub to acknowledge anything, so they advertise
  their latest report without queueing it.

## What a change needs deployed

| Change | Needs | Notes |
| --- | --- | --- |
| Sensor firmware | Build and flash; bump `sensor/version.txt` | By USB with `flush.sh` when the C3 is plugged in; over the air through the hub otherwise |
| Rename or refactor with identical bytes on air and in flash | Nothing on the device | The running firmware stays compatible |
| Hub code | Restart the hub service | `launchctl kickstart -k gui/$(id -u)/com.openplantpulse.hub`; it runs from the main checkout |
| Hub database schema | Rehearse on a copy, back up, restart | The migration runs at start; every step so far kept every row |
| Contract (what a packet carries) | Hub and sensor together | Restart the hub, then flash at once; the queue records its packet format and discards reports of an older one at boot, which the new hub could never accept |
| Documentation | Nothing | |

Before pushing, run `sh scripts/check.sh`. CI runs the same on Linux with GCC
in strict C11, which is stricter than macOS: POSIX-only functions such as
`strnlen` fail there. Code the host tests compile must be standard C.

## Shared data contract and identity

Shared contracts are defined in [`protocol/`](../protocol/README.md): BTHome
contract v3, whose two packets per report and exact byte budget are laid out in
its "Byte budget and worked example" section. There is one contract at a time;
a change replaces it in the sensor encoder, hub decoder and fixtures together.

Each stored sample needs at least:

- an enrolled hub sensor ID and documented observed BLE identifier;
- hub receipt time in UTC;
- available measurements in canonical units, with failed sources explicit and
  unavailable measurements absent;
- BTHome contract version and bounded receive diagnostics such as RSSI; and
- the sensor's report ID, which never repeats: the hub keys each report by
  `(sensor, report ID)`, so repeats are duplicates and a backfilled report
  lands in its place.

Bluetooth identifiers differ by platform and may change. Linux commonly exposes
an address while macOS exposes a CoreBluetooth UUID. Neither is automatically a
portable sensor identity. The BTHome contract must define a stable identity or the
prototype UI must state the scope of observed identifiers and support deliberate
replace/merge handling.

## Failure and trust boundaries

- Reject malformed or unsupported advertisements without terminating scanning or
  writing partial samples.
- Never reuse cached source values after a failed measurement.
- Distinguish sensor staleness from a failed Bluetooth adapter.
- Bind household HTTP to loopback by default and require explicit LAN exposure.
- Treat the existing BTHome payload and device-configuration GATT service as
  observable and unauthenticated prototype interfaces.
- Do not log encryption keys, Wi-Fi passwords, MQTT credentials, or Home Assistant
  tokens.
- Predictions are advisory; actuator control requires a separate safety design.

## References

- [BTHome v2 format](https://bthome.io/format/)
- [Bleak documentation](https://bleak.readthedocs.io/)
- [ESP-IDF NimBLE guide](https://docs.espressif.com/projects/esp-idf/en/stable/esp32c3/api-reference/bluetooth/nimble/index.html)
- [XIAO ESP32-C3 documentation](https://wiki.seeedstudio.com/XIAO_ESP32C3_Getting_Started/)

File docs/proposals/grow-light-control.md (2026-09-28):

# Grow light control

## Status

Accepted 2026-09-27. Implemented, and cut over on the hub computer on
2026-09-27: both lights are driven by the hub and confirmed on and off, and the
schedule switched them on at a window edge and held them through a hub restart.
The GL1C's colour by eye, an off edge, and network-drop recovery are still to
check.

## Decision and scope

The hub manages lights, and each light's type is handled by its own driver. A plant
picks which lights it uses and owns its own lighting schedule. A light belongs to
at most one plant. One scheduler in the
hub turns the chosen lights on and off. It replaces the standalone `gl1cd`
controller rather than talking to it.

The device protocols come from the working `glowlight` project: `gl1cd.py`,
the controller that ran both lights before the hub, and its `HARDWARE.md`
protocol notes. The drivers in `hub/src/open_plant_pulse_hub/lighting/` carry
the facts that matter in their docstrings.

In scope for the first release:

- A **Lights** page to add, rename and remove lights. Adding a light means picking a
  light type (Neewer GL1C, Wemo-switched light) and filling in that type's
  connection settings.
- A **driver** per light type that hides how the light is controlled. The rest of the
  hub only asks a driver to turn a light on or off and to report its current state.
- On a plant's pages, a **light picker** for one or more lights, and a **lighting
  schedule editor** for that plant.
- A **scheduler** in the hub that turns schedules into on/off commands, confirms
  each one, corrects drift and backs off after manual control. It carries over the
  rules that already work in `gl1cd`.
- **Manual on/off** for each light from the Lights page.

Out of scope for now: colour scenes over the day (sunrise ramps), light-level
sensing, lights shared across hubs, and any vendor cloud. The GL1C's colour preset
stays a per-light setting, not part of the schedule.

## Data model

Three new tables in schema version 21: `lights`, `plant_lights` and
`plant_light_schedules`, plus a `light_events` log. The schedule hangs off
`plants.plant_id`, not off a light or a sensor, so it belongs to the plant and
survives replacing its sensor (`replace_sensor` already carries `plant_id` over).

Today a plant row is created when a sensor is adopted (`manage_sensor`) and deleted
when its last sensor is deleted (`delete_sensor`), and the UI addresses plants by
sensor id. The new tables key on `plant_id`; the API keeps taking a sensor id and
the store resolves it to the plant.

| Table | Columns | Notes |
| --- | --- | --- |
| `lights` | `light_id` (text, e.g. `light-3f2a`), `display_name`, `driver` (`neewer-gl1c`, `wemo-switch`), `config` (JSON), `created_at` | `config` is owned by the driver: the GL1C holds `mac`, `last_ip`, `preset {brr, cct, gm}`; the Wemo holds `host`, `last_port`. The hub never reads inside it. |
| `plant_lights` | `light_id` (primary key), `plant_id` | A plant can use several lights; a light belongs to at most one plant, so two schedules never compete for it. Deleting a light removes its link. |
| `plant_light_schedules` | `plant_id` (primary key), `enabled`, `on_time` (`HH:MM`), `off_time` (`HH:MM`), `updated_at` | One daily window per plant, in the hub's local time. It may wrap midnight. `on_time = off_time` is refused. |
| `light_events` | `event_id`, `light_id`, `at`, `source` (`schedule`, `watchdog`, `manual`), `wanted`, `outcome`, `detail` | A short log for the Lights page and for debugging, trimmed like the receive diagnostics. |

Runtime state (online, last known power, subscribed, manual override deadline) stays
in memory in the light service, as `gl1cd` does. Only facts a driver learns and must
keep, such as the GL1C's MAC or new IP, are written back into `lights.config`.

## Driver abstraction

Every light type is a driver class registered under a name. The scheduler, API and
pages only call this interface; everything device-specific (UDP sessions, SOAP, port
walks, colour presets) stays inside the driver.

```python
class LightDriver(Protocol):
    kind: str                      # "neewer-gl1c", "wemo-switch"
    label: str                     # shown in the Add light form
    config_schema: dict            # fields the Add/Edit form renders and validates
    capabilities: set              # {"power"} or {"power", "level", "colour"}

    def start(self) -> None: ...   # open sockets, start its own threads
    def stop(self) -> None: ...
    def state(self) -> LightState: ...            # cached: online, power (0/1/None), detail; never blocks
    def set_power(self, on: bool) -> Result: ...  # acts and confirms; may take seconds
    def config_updates(self) -> dict: ...         # facts learned (new IP, MAC) for the hub to persist
```

- **`state()` never waits on the device.** It returns what the driver last confirmed
  and reports power as unknown when the device is stale, as `gl1cd` does after a
  stale "on" hid a 90-minute outage.
- **`set_power()` confirms before it returns.** The GL1C waits for its 0x07 report;
  the Wemo reads `GetBinaryState` back. A result is `confirmed`, `unconfirmed` or
  `unreachable`, with a reason.
- **Each driver instance owns its own threads and locks.** One slow Wemo port walk
  (up to about 50 s) can never delay the GL1C.
- **Adding a light type later** means one new driver module and one registry entry,
  with no change to the scheduler, API or pages. The form is built from
  `config_schema`.

| Driver | Transport | Capabilities | Config | Carried over from `gl1cd` |
| --- | --- | --- | --- | --- |
| `neewer-gl1c` | UDP 5052 session: handshake, subscribe, 1 Hz keepalive | power, level, colour | `mac`, `last_ip`, `preset` | Beacon discovery by MAC, subnet sweep, re-subscribe, send colour twice after power-on, 0x07 confirmation |
| `wemo-switch` | HTTP SOAP on ports 49152–49155 | power | `host`, `last_port` | Port walk twice with 3 s timeouts, read back after every set, per-switch lock, 35 s staleness |

The Sansi light is added as a `wemo-switch` light named "Sansi 36W": the hub
controls the outlet, and the light's name is just what you call it. Only one GL1C
driver instance may bind UDP 5052, so a second GL1C would share one session socket
inside the driver; that stays out of the first release.

## Architecture

The light service runs inside the hub process beside BLE ingestion and the web
server, on its own threads, so a stuck light never blocks readings or pages.

```mermaid
flowchart TB
    LightsPage[Lights page\nadd, rename, remove\nlive state, manual on/off] --> API
    PlantPage[Plant pages\nchoose lights\nedit lighting schedule] --> API
    API[Hub HTTP API, web.py] --> Service
    API --> Store
    Service[Light service\nscheduler, watchdog,\nmanual override, event log] -->|reads, logs| Store[(SQLite\nlights, plant_lights,\nplant_light_schedules,\nlight_events)]
    Service --> Iface
    subgraph Iface[Driver interface: state, set_power, config_updates]
        GL1CDriver[neewer-gl1c driver\nUDP 5052 session\nfinds light by beacon MAC]
        WemoDriver[wemo-switch driver\nSOAP on 49152–49155\nreads back after each set]
    end
    GL1CDriver -->|UDP| GL1C[Neewer GL1C]
    WemoDriver -->|HTTP| Wemo[Wemo switch F7C027] --> Sansi[Sansi 36W]
```

The pages only talk to the API; the light service is the only caller of drivers;
drivers are the only code that knows a device's protocol.

## Scheduling

The scheduler works per light: each light follows the schedule of the one plant that
owns it, with `gl1cd`'s proven rules.

**Wanted state of a light.** A light is wanted **on** when its plant has an enabled
schedule and is inside its window now, and **off** when it is outside. It has **no
wanted state** when it belongs to no plant, its plant is archived, or its plant's
schedule is disabled; the scheduler then leaves it alone, and only manual control
applies.

```text
every tick (10 s), for each light, on that light's own worker:
  plant  = the light's plant, if it is active and its schedule is enabled
  if no plant:              last_wanted = none; skip           # manual-only light
  want   = in_window(plant, now)
  edge   = want != last_wanted                                  # true on the first tick after start
  state  = driver.state()
  if state.power is None and not edge: skip                     # nothing to compare
  if not edge and (watchdog off or now < override_until): skip
  if state.power == want:   last_wanted = want; skip
  result = driver.set_power(want)                               # confirms, or reports why not
  log light_events(source = edge ? schedule : watchdog, result)
  if result.confirmed:      last_wanted = want
  else:                     set the light's alert; retry next tick
```

| Situation | Behaviour |
| --- | --- |
| Hub starts mid-window | First tick is an edge, so the scheduled state is asserted |
| Plant picks a light another plant owns | Refused; the picker shows which plant owns it |
| Schedule edited, light linked or unlinked | That light's `last_wanted` is reset, so the change applies on the next tick |
| Manual on/off from the Lights page | Pauses drift correction on that light for 60 minutes; a window edge still acts |
| Driver reports unreachable | Light shows an alert on the Lights page and on each plant using it; retried every tick |
| GL1C lost mains power | Unrecoverable in software; the alert says to press the light's button |
| `on_time` equals `off_time` | Refused by the API |

Times are the hub computer's local time, as `gl1cd` used. Each light's commands run
on its own worker, so a 50-second Wemo port walk never delays the GL1C.

## API and pages

Lights management becomes a **Lights** tab in Settings (`/settings/lights`, beside
Sensors, Rooms, Wi-Fi and Firmware), and a plant's lights and schedule go on the
plant's own pages. Plant routes keep using the sensor id, as every current plant
route does, and the store resolves it to `plant_id`.

| Method and path | Body | Does |
| --- | --- | --- |
| `GET /api/light-drivers` | — | Lists light types with their label, capabilities and config fields, so the Add form is built from the driver |
| `GET /api/lights` | — | All lights with name, type, live state (online, power, alert), the plants using them and recent events |
| `POST /api/lights` | `display_name`, `driver`, `config` | Adds a light; the driver validates `config` and starts |
| `PUT /api/lights/<id>` | `display_name`, `config` | Renames or reconfigures a light; the driver restarts if `config` changed |
| `DELETE /api/lights/<id>` | — | Stops the driver, removes the light and its plant links; the light is left in whatever state it was |
| `POST /api/lights/<id>/power` | `on` | Manual on/off: waits for confirmation (up to about 30 s for a Wemo) and starts a 60-minute override |
| `GET /api/sensors/<id>/lighting` | — | The plant's linked lights with their state, and its schedule |
| `PUT /api/sensors/<id>/lighting` | `light_ids`, `schedule {enabled, on, off}` | Replaces the plant's light links and schedule in one save; refused if a light belongs to another plant |

Pages:

- **Settings › Lights.** A list of lights, each with its name, type, state (on, off,
  unreachable, alert) and which plants use it; buttons to turn it on or off, rename,
  edit settings and remove it. **Add light** opens a form: pick a type, then fill in
  that type's fields (GL1C: nothing required, as it is found on the network and its
  MAC is learned; Wemo: IP address). Removing a light used by plants asks first and
  names them.
- **Plant page.** A **Lighting** card showing the chosen lights, their state now,
  and today's window ("on 08:00, off 21:30, on now"). It links to the plant's
  configure page.
- **Plant configure page** (`/sensors/<id>/settings`). A **Lighting** section with
  checkboxes for the hub's lights (a light owned by another plant is shown
  greyed out with that plant's name), a schedule switch, and on and off time inputs. It
  saves with `PUT /api/sensors/<id>/lighting`.

All writes keep the existing same-origin check in `web.py`, and the management
server stays on loopback, so no one on the network can switch the lights through it.

## Delivery

Build it in six steps, each landing with its own tests, so the GL1C and Sansi move
over only after the hub side is proven with fake drivers.

1. **Schema and store.** Migration 21 adds `lights`, `plant_lights`,
   `plant_light_schedules` and `light_events`. Add store methods for lights, links
   and schedules. Test the migration and the plant/sensor id resolution, and check
   that deleting a plant's last sensor removes its links and schedule too.
2. **Driver interface and a fake driver.** `lighting/driver.py` holds the interface,
   the registry and a `fake` driver for tests and for trying the pages without
   hardware.
3. **Light service and scheduler.** One worker per light, the per-tick rules above,
   override, alerts and the event log. Unit tests cover the 12 cases in the `gl1cd`
   spec, plus the new ones: a light with no plant, an archived plant, and a light
   moved from one plant to another.
4. **API and pages.** The routes above, the Settings › Lights tab, the Lighting card
   and the configure section. HTTP tests follow `test_sensor_management.py`.
5. **Real drivers.** Port `neewer-gl1c` and `wemo-switch` from `gl1cd`. Unit-test the
   frame bytes (`80 04 00 84`, `80 06 01 01 88`, `80 05 02 01 01 89`, preset
   `80 05 04 02 64 2a 32 4b`), beacon MAC parsing and SOAP parsing.
6. **Cut-over on the hub computer.** Stop and disable `com.keefo.gl1cd` and
   `com.keefo.gl1cmenu` (only one process can hold UDP 5052), restart
   `com.openplantpulse.hub`, then add both lights and link them to plants. Seed the
   GL1C's config with its beacon MAC from
   `~/Library/Application Support/gl1c/config.json`.

Hardware checks after cut-over, each recorded in the worklog with evidence:

- [ ] Lights page shows the GL1C online and subscribed within about 10 s, and the
      Sansi's state in under a second.
- [ ] Manual off, then on, for each light is confirmed by the device (0x07 report;
      Wemo read-back).
- [ ] After a GL1C power-on, the light's own display reads 100 % and 4200 K. This is
      the only check of the colour byte order.
- [ ] Restarting the hub mid-window leaves both lights in the scheduled state.
- [ ] Unplugging the hub computer's network for a minute: both lights come back
      online without a restart.

The risk flagged here was real: on macOS 15 the launchd hub needs Local Network
permission to reach the GL1C and the Wemo, and it cannot even be asked for while
the app's main executable is a shell script. The bundle now has a compiled
launcher and `NSLocalNetworkUsageDescription`; see "Running as a macOS service"
in `docs/hub.md`.

## Decisions

Settled on 2026-09-27:

- **Lights page:** a Lights tab in Settings, at `/settings/lights`.
- **Sharing:** a light belongs to at most one plant.
- **GL1C colour:** brightness, CCT and tint are a setting on the light, applied on
  every power-on.
- **Starting schedule:** a plant's first schedule is 08:00 to 21:30, enabled, the
  window `gl1cd` runs today.
- **Plants without a sensor** cannot have lights yet, because plants exist only
  through an enrolled sensor.
- **Removing a light** leaves it in whatever state it is in.
- **Old controller:** at cut-over the `gl1cd` services are disabled, not uninstalled,
  and only after confirming with the owner.

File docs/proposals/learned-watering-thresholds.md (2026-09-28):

# Learned watering thresholds

## Status

Proposed 2026-09-28. Not implemented. The plant profiles' generic moisture
targets were lowered for the bird of paradise the same day as a stopgap; this
proposal replaces generic targets with ones learned from each sensor's own pot.

## Goal

Tell the user when to water from how *their* pot behaves, not from generic
numbers. After one full watering cycle, each sensor's watering thresholds come
from its own pot, soil and probe depth. The plant profile keeps saying what kind
of plant it is; the pot supplies the numbers.

## Why generic targets fail

The soil probe reports volumetric water content calibrated for mineral soil.
The same plant reads very differently depending on things the profile cannot
know:

- **Soil.** An airy bark and perlite mix holds less water by volume than garden
  soil, and its air gaps lower the reading further. "35 %" in one pot and "35 %"
  in another are not the same condition.
- **Depth and placement.** Near the surface the soil dries first; near the
  bottom water collects. The probe reads the zone around its needles.
- **Pot.** Size, material and drainage change how fast the whole cycle runs.

Measured on the first sensor, a bird of paradise in an airy mix with the probe
10 cm deep: about 17 % six days after watering, in a watering rhythm of about 23
days that suits the plant, and about 53 % two minutes after a watering, still
draining. The strelitzia profile then said refill below 35 % and concern below
20 %, so the hub would have asked for water every three to five days. For a plant
whose main risk is root rot from overwatering, that is the dangerous direction.

## What is learned

Per sensor, from its own readings:

| Value | Meaning | How it is measured |
| --- | --- | --- |
| Full level | Moisture once a thorough watering has drained | Median moisture from 12 to 36 hours after a full watering |
| Refill point | The level at which the user actually waters | Moisture just before the next full watering |
| Dry-down rate | How fast the pot dries | Percentage points per day between the two |

The dry-down rate is not used for thresholds; it is kept for a later "water in
about N days" forecast.

## Recognising a full watering

The hub already records a watering as a care event when moisture rises by at
least 15 points (`WATERING_RISE_PERCENT`), and watches drainage settle
(moisture within 1.5 points for 20 minutes, `DRAINAGE_SETTLE_WINDOW`). A watering counts for learning
only if it is **full**: moisture reaches near saturation and then settles.

A small top-up, like the half cup poured at the probe on 2026-09-27 to test its
contact, rises steeply at the probe but does not wet the pot through. Those are
marked partial and ignored, so they cannot pull the full level or the refill
point. What "near saturation" means for a given pot is itself learned: the first
cycles use a generous rule (a rise of at least 25 points, peaking above 60 %),
and later ones compare against the pot's own previous peaks.

## Deriving thresholds

| Threshold | Derived from |
| --- | --- |
| Refill below | The learned refill point |
| Comfortable cycle | Refill point up to full level |
| Target after watering | Full level, plus or minus a few points |
| Concern below | About 60 % of the refill point: overdue |
| Concern above | Full level plus a margin, **sustained beyond the settle time**: not draining |

"Concern above" is the warning that matters most for a plant prone to rot. It
fires only when the pot stays wetter than its own full level after drainage
should have finished, never during the minutes of soaking right after a
watering.

The profile's defaults act as a fence, not the source. A learned value is
adopted only if it is plausible: the refill point between concern-low and the
full level, and the full level above the refill point by a clear margin. If it
falls far outside the plant's plausible band, the hub asks the user rather than
adopting it silently.

## Adapting over time

The values are a rolling average over the last three complete cycles. Summer
drying faster, winter slower, and a growing plant all move the numbers smoothly;
one odd cycle cannot swing them. A cycle is complete when a full watering is
followed by another full watering.

## States

On the sensor's page:

- **Calibrating: first cycle.** The profile's defaults are in use until one
  complete cycle has been observed. The page says so and what it is waiting for
  ("next full watering").
- **Learned from N cycles.** The learned values, with the dates of the cycles
  they came from.
- **Manual.** The user sets the numbers; learning continues in the background
  but does not replace them. This extends the existing per-sensor
  `moisture_low_percent` override to the whole set.
- **Recalibrate.** For after moving the probe or repotting: learning starts over,
  because the old numbers describe a different placement.

## Storage

A small per-sensor calibration table: full level, refill point, dry-down rate,
the number of cycles and the report IDs that bound each, last updated, and mode
(calibrating, learned, manual). One forward migration, rehearsed on a copy of the
live database and backed up before it runs, as every migration so far.

The care-event detector (`domain/care_events.py`) keeps using a single
`refill_below` per sensor; it reads it from the calibration when one exists,
from the manual value in manual mode, and from the profile otherwise.

## Plan

1. Classify waterings as full or partial, from the existing watering and
   drainage observations, and record the classification.
2. Compute full level, refill point and dry-down rate per complete cycle, and the
   rolling values.
3. Derive thresholds with the plausibility fence; store them with their mode.
4. Feed the care-event detector and the page from the stored thresholds.
5. Sensor page: the state, the learned values and their cycles, Manual and
   Recalibrate.

## Validation

- Unit tests on synthetic cycles: full and partial waterings, a noisy cycle, a
  seasonal drift, a recalibration, a value outside the plausible band.
- Replaying the first sensor's real history once it has a couple of complete
  cycles. With a rhythm of about 23 days, the first learned values arrive after
  the next full watering and the one after it.
- On the page: every state rendered, and a manual value surviving learning.

## Not in this proposal

- Watering forecasts ("water in about N days"), which the dry-down rate enables.
- Learning from the air sensor or the season directly, beyond what the rolling
  average absorbs.
- Changing the probe's own moisture calibration; the thresholds absorb it.

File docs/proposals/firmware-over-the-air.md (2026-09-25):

# Firmware over the air

## Status

Implemented 2026-09-25 and validated on one sensor. Firmware 0.12.1 was installed
over the air in about fifteen seconds, and a deliberately broken image was rolled
back without help. What has and has not run on hardware is in the worklog.

## Goal

Keep a built firmware image on the hub, and update a sensor from the browser
without a cable. One button, on the sensor's own configuration page.

Today every sensor in the house has to be unplugged, carried to a computer, and
flashed over USB. That is acceptable for one sensor on a bench and unacceptable
for a household with several, which is what the rest of this project assumes.

## Two links, two jobs

**The hub commands over Bluetooth. The sensor downloads over Wi-Fi.**

The bonded BLE link is the authenticated one: only the hub that owns a sensor can
connect to it at all, and the configuration characteristic already requires
encryption. It is the right place to say *install this image*. It is the wrong
place to move 1.3 MB: at the throughput this link achieves, the transfer would
take minutes with the radio held open throughout, and any interruption would
restart it.

The sensor is already on the household network whenever its console is on, and
ESP-IDF's `esp_http_ota` streams an image into the spare slot at Wi-Fi speed with
resumable framing, header validation, and rollback support already written. So the
command carries an address, and the sensor fetches.

The consequence is a precondition, stated plainly in the interface: **a sensor can
only be updated while it is on the household network.** If its console is off, the
button says so rather than failing later.

## What the hub stores

An uploaded image is not trusted because somebody said it was firmware. The hub
reads the ESP-IDF application descriptor out of the file and refuses anything that
is not an `esp32c3` image of this project:

| Checked | Where | Refusal |
| --- | --- | --- |
| Image magic `0xE9` | byte 0 | not an ESP-IDF image |
| Chip ID 5 | header byte 12 | built for another chip |
| Descriptor magic `0xABCD5432` | offset 0x20 | no application descriptor |
| Project name `open_plant_pulse` | descriptor | another project's firmware |
| Version | descriptor | — it is read, never typed |

The version therefore comes from the image, not from a form field, and cannot
disagree with what the sensor will report after it boots.

Images live in `~/.open-plant-pulse/firmware/<sha256>.bin` with a row recording
size, digest, version, project, IDF version and upload time. The digest is the
identity: uploading the same image twice stores it once.

## The command

Protocol version 7 on the existing configuration characteristic, alongside
configuration (6), credentials (3), release (5) and report acknowledgement (1).
Forty-seven bytes:

| Bytes | Meaning |
| --- | --- |
| 0 | 7 |
| 1–4 | update ID, so a repeat of one already running is ignored |
| 5–8 | image size |
| 9–12 | hub IPv4 address |
| 13–14 | hub port |
| 15–46 | SHA-256 of the image |

The sensor builds `http://<address>:<port>/firmware/<digest>.bin` from it. Nothing
in the command names a file, so a compromised command cannot ask the sensor to
fetch something else from the hub.

## What the sensor answers

The configuration read-back already carries a station-status suffix (marker
`0xA1`). Update progress is a second suffix, marker `0xA2`, placed **before** it,
so a hub that reads the last nine bytes still finds the station status where it
was. Four bytes: marker, state, percent, failure reason.

The hub polls it while an update is in flight, on the connection it already makes
when something is pending.

Success is not taken from that report, though. Success is the sensor coming back
and reporting the new version in its station status. A sensor that says it
installed an image and then does not return has not succeeded.

## Safety

- **Integrity.** The command carries the digest; the sensor hashes what it writes
  and refuses an image that does not match. ESP-IDF separately validates the image
  header and its checksum before the bootloader will run it.
- **Rollback.** Two OTA slots with `CONFIG_BOOTLOADER_APP_ROLLBACK_ENABLE`. A new
  image boots as pending; it marks itself valid only once it has reached the point
  of advertising, which is the sensor's whole job. An image that crashes first is
  replaced by the previous one at the next reset, without anybody's help.
- **Authority.** The command arrives only over the bonded, encrypted link, from
  the one hub that owns the sensor.
- **Exposure.** The management API stays on loopback. Images are served by a
  separate read-only server on the household network, which answers exactly one
  shape of request and holds nothing private: the firmware is the same file this
  repository builds.

## Partitions

OTA needs two application slots, which the current single-app layout does not
have, and 4 MB of addressable flash, which the current 2 MB header does not have
although the board has always had the flash.

```
nvs,      data, nvs,     0x9000,   0x6000
otadata,  data, ota,     0xF000,   0x2000
phy_init, data, phy,     0x11000,  0x1000
ota_0,    app,  ota_0,   0x20000,  0x190000
ota_1,    app,  ota_1,   0x1B0000, 0x190000
```

`nvs` keeps its offset and size, so the one cable flash that introduces this
layout does not cost the sensor its bond, its pairing code, or its configuration.

**This first step needs a cable.** A partition table cannot be replaced over the
air by the application it is replacing. Every update after it can.

## States

Per sensor, alongside the existing configuration state:

| State | Meaning |
| --- | --- |
| `idle` | nothing requested |
| `pending` | an image is chosen; the command has not reached the sensor |
| `commanded` | the sensor has taken the command |
| `downloading` | the sensor is fetching, with a percentage |
| `installing` | written; switching slots |
| `rebooting` | the sensor has gone to restart |
| `succeeded` | the sensor came back reporting the target version |
| `failed` | with a reason: unreachable, download, digest, flash, or rejected |

## Plan

1. **Hub storage.** Image parsing, the image table, and the files on disk.
2. **Hub interface.** Upload and list images in Settings; choose and start an
   update on a sensor's configuration page; show progress.
3. **Hub delivery.** Encode the command, send it on the next advertisement the
   way configuration is sent, poll progress, and recognise the returning version.
4. **Sensor.** Partitions and flash size, the update task, the progress suffix,
   rollback confirmation, and staying awake while an update runs.
5. **Validation.** Host tests throughout; then a cable flash of the first
   OTA-capable image, and an update of that sensor over the air.

## Validation

Host checks, build, flash, and device behaviour are separate claims.

- [x] An uploaded image is parsed, stored once per digest, and served.
- [x] Anything that is not an `open_plant_pulse` esp32c3 image is refused.
- [x] The command encodes and decodes, and is distinguishable from every other
      payload version on the characteristic.
- [x] The whole flow is covered by host tests with no hardware.
- [x] The OTA-capable image builds and is flashed by cable, keeping its bond.
- [x] A sensor updates over the air and returns reporting the new version.
- [ ] An image that does not match its digest is refused by the sensor. The hub
      cannot serve a mismatching image — it checks the file against the name it
      is stored under — so proving this needs a server that is trying to, which
      has not been built.
- [x] A deliberately broken image rolls back without help, and the hub says so
      rather than saying "restarting" for ever.

## Not in this proposal

- Updating several sensors at once. One at a time first.
- Downloading images from the internet. The hub serves what somebody put on it.
- Signed images. Worth doing, and a different piece of work: it needs a key that
  outlives any one hub, and secure boot to mean anything.

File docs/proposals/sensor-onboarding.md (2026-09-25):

# Sensor onboarding

## Status

Proposed. Nothing implemented.

## Goal

A customer brings home a new sensor that has never seen a router or a hub. Two
things must happen, with no terminal, no reflash, and no app:

1. The sensor registers with exactly one hub.
2. The sensor receives the household Wi-Fi credentials.

## Interface

A clickable mockup of the screens this proposal describes:
<https://claude.ai/artifact/XLLYZUCgwiATupGBLzLCwr>. It covers a Settings page with
Sensors and Wi-Fi tabs, and the four-step Add a sensor flow. The link is private to
the repository owner and will not open for anyone else.

The screens establish three things the text alone does not: the household network is
entered once and sensors carry only a switch, the pairing step is where the
platform's own dialog appears, and onboarding ends with a measured reading rather
than a promise.

## States

The sensor has two states. The state is **derived from whether a BLE bond exists**,
not stored separately, so it cannot disagree with reality.

| State | Condition | Behaviour |
| --- | --- | --- |
| Onboarding | no bond | Advertise connectably, accept one pairing attempt, refuse all configuration access |
| Onboarded | bond present | Advertise telemetry, accept connections only from the bonded hub, allow configuration over the encrypted link |

A factory-fresh sensor is in onboarding. A reset returns it there. There is no
other way back, which is what makes "one sensor, one hub" true rather than
merely conventional.

`/status` exposes the state so the console and the hub inbox agree.

## Key decision

**The hub is the onboarding interface. The sensor never raises an access point.**

BLE already connects them and needs no router. The sensor advertises connectably
today (`BLE_GAP_CONN_MODE_UND`), the hub already discovers unenrolled sensors into
an inbox, and it already writes configuration over a characteristic and verifies
it by read-back. This removes the access point, the captive portal, the DNS
redirects, and the hotspot-switching step from the customer's experience, along
with their flash cost. Firmware 0.5.0 left about 17% of the app partition free and
there is no OTA.

## Handshake

Use BLE LE Secure Connections. Do not design a key exchange.

LE Secure Connections performs ECDH on P-256: both sides exchange public keys and
each independently **derives** the same Long Term Key. **The LTK is never
transmitted**, so a passive listener that captures the entire handshake cannot
compute it. `CONFIG_BT_NIMBLE_SM_SC` is already enabled in the build; the firmware
simply never configures or uses it. Legacy pairing must not be accepted as a
fallback, because it does distribute keys and is recoverable by a sniffer.

### Proving ownership, and defeating an active attacker

Just Works pairing has no man-in-the-middle protection, and the ESP32-C3 has no
display or keypad. The answer is a **six-digit passkey generated once at first
boot and printed on the device label**, entered into the hub at enrolment with
`sm_io_cap = BLE_HS_IO_DISPLAY_ONLY`.

One mechanism solves two problems. It gives real man-in-the-middle protection, and
it proves the person enrolling physically holds the device, so a neighbour's hub
cannot claim the sensor and the customer cannot accidentally enrol the neighbour's.
It also avoids depending on a button, which matters: the firmware reads no GPIO
today, and the enclosure exposes none.

The passkey is device identity, not a bond. It lives in its own NVS namespace and
**a reset must not erase it**.

### Firmware configuration

```c
ble_hs_cfg.sm_sc          = 1;   /* Secure Connections, not legacy */
ble_hs_cfg.sm_bonding     = 1;   /* keep the derived key */
ble_hs_cfg.sm_mitm        = 1;   /* require the passkey */
ble_hs_cfg.sm_io_cap      = BLE_HS_IO_DISPLAY_ONLY;
ble_hs_cfg.sm_our_key_dist = BLE_SM_PAIR_KEY_DIST_ENC | BLE_SM_PAIR_KEY_DIST_ID;
```

and the configuration characteristic re-declared from today's bare
`BLE_GATT_CHR_F_READ | BLE_GATT_CHR_F_WRITE` (`bthome_broadcaster.c:99`) to
`READ_ENC | WRITE_ENC`, so NimBLE refuses access on an unencrypted link.

## What the encryption does and does not cover

**Connections are encrypted by the controller.** Application code never touches the
LTK and never calls an encryption function. After bonding, each new connection
starts unencrypted, the hub requests encryption from the stored key, and only then
does the `_ENC` flag allow configuration access. That brief unencrypted window is
exactly why the flag matters.

**Advertisements are not covered by the LTK.** BTHome telemetry is broadcast, not
sent over a connection, so link encryption is irrelevant to it. Contract v2 keeps
device-info byte `0x40`, unencrypted, and `protocol/README.md` already records that
measurements, identifiers, and device presence are observable.

They are covered instead by a BTHome bind key, and **that is on by default**.
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

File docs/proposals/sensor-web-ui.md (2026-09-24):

# Sensor web UI redesign

## Status

Proposed development-only diagnostics interface for the ESP32-C3 sensor node.

## Purpose

Replace the current embedded single-page log viewer with a maintainable device
console while retaining ESP-IDF's Apache-2.0 `esp_http_server`. The console is
for bench development, bring-up, and fault diagnosis. It is not the product's
historical dashboard; long-term readings, analytics, plant care, and Home
Assistant integration remain responsibilities of the hub.

The production sensor remains deep-sleep and battery-oriented. It will emit one
bounded BTHome advertising burst per wake; the continuously available Wi-Fi web UI
must stay optional and be disabled for power measurements and deployed low-power
builds. Sensor Wi-Fi/HTTP reporting is lower-priority evaluation work.
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

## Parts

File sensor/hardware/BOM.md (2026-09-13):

# Bill of materials

The canonical project BOM is [`bom.csv`](bom.csv). CSV is used because it is
diffable, works with spreadsheets and procurement tools, and can later be
generated from KiCad. Keep it UTF-8 and RFC 4180 compatible, with one physical
line item per row.

The BOM describes one complete Open Plant Pulse assembly. It is currently a
planning BOM, not an approved purchasing list. Rows marked `selection_required`
or containing `TBD` must be resolved before hardware is ordered for a release.
All current numeric `unit_cost` values are estimates in Canadian dollars (CAD),
as recorded by each row's `currency` field. Costs exclude tax and shipping.

Validate it locally after any change:

```sh
python3 scripts/validate-bom.py
```

## Columns

| Column | Meaning |
| --- | --- |
| `item_id` | Stable project identifier; never reuse an ID for a different part |
| `category` | Broad grouping such as electronics, sensor, power, or mechanical |
| `description` | Vendor-neutral functional description |
| `quantity` / `unit` | Amount required for one complete assembly |
| `manufacturer` | Original part manufacturer, not the marketplace seller |
| `manufacturer_part_number` | Exact orderable MPN; use `TBD` until confirmed |
| `form_factor` | Physical package, module footprint, connector pitch, or assembly format |
| `supplier` / `supplier_sku` | Preferred purchasing source and its stock code |
| `unit_cost` / `currency` | Reference price per unit and ISO 4217 currency code; current estimates use CAD |
| `procurement_url` | Stable manufacturer or distributor page when possible |
| `revision` | Hardware or drawing revision known to have been validated |
| `status` | Selection and validation state defined below |
| `notes` | Constraints that do not fit another field |

## Status values

- `selection_required`: alternatives exist but no exact part has been chosen.
- `candidate`: an intended part class is recorded but not fully validated.
- `validated`: the exact MPN/revision passed the bring-up checklist.
- `obsolete`: retained for history but must not be used for new builds.
- `design_required`: a project-authored part does not yet have released source.

## Maintenance rules

1. Use an exact manufacturer part number for every purchased item. Product names
   such as "RS485 board" or "18650" are not sufficient for a release.
2. Describe the physical implementation precisely. Castellated edge pads and
   through-hole pin headers are different termination styles even when both fit
   a standard 2.54 mm (0.1 in) breakout footprint.
3. Record alternates as separate rows or in an approved-alternates file after
   proving form, fit, function, electrical, and firmware compatibility.
4. Treat prices as dated estimates. Update them for a release and state the
   pricing date, currency, tax, and shipping assumptions in the release notes.
5. Do not silently replace a validated revision. Change the row and repeat the
   affected bring-up tests.
6. For a future custom PCB, generate its component BOM from KiCad and list the
   populated PCB as a subassembly in this top-level assembly BOM.

## Release process

For each hardware release:

1. Resolve all required `TBD` fields and freeze exact revisions.
2. Copy the canonical BOM into the release artifacts with the release version in
   its filename, for example `open-plant-pulse-bom-v1.0.csv`.
3. Export a human-readable PDF or spreadsheet only as a convenience artifact;
   the tagged CSV remains the source of truth.
4. Include total reference cost and any minimum-order quantities in release notes.

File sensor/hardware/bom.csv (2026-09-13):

item_id | category | description | quantity | unit | manufacturer | manufacturer_part_number | form_factor | supplier | supplier_sku | unit_cost | currency | procurement_url | revision | status | notes
CTRL-001 | electronics | Seeed Studio XIAO ESP32-C3 | 1 | each | Seeed Studio | TBD | XIAO 21 x 17.8 mm castellated module with 2.54 mm pin-header support | TBD | TBD | 12.60 | CAD | https://wiki.seeedstudio.com/XIAO_ESP32C3_Getting_Started/ | TBD | candidate | Brainstorm price estimate; confirm purchasable MPN and board revision
IFACE-001 | electronics | RS485 expansion board for XIAO with boost supply | 1 | each | Seeed Studio | TBD | XIAO stackable breakout | TBD | TBD | 7.30 | CAD | TBD | TBD | selection_required | Brainstorm price estimate; confirm product input range output current enable pin and idle current
PROBE-001 | sensor | NPKPHCTH-S seven-parameter RS485 soil probe | 1 | each | ComWinTop | NPKPHCTH-S | IP68 wired 316 stainless-steel insertion probe | TBD | TBD | 57.80 | CAD | TBD | TBD | candidate | Measures soil nitrogen phosphorus potassium pH conductivity temperature and moisture over Modbus RTU; verify exact register map scaling supply range cable colors and product revision
SENSOR-AIR-001 | sensor | SHT45 air temperature and relative humidity sensor breakout | 1 | each | Sensirion | TBD | Standard 2.54 mm (0.1 in) pin-header solder-pad breakout | TBD | TBD | TBD | CAD | https://sensirion.com/products/catalog/SHT45 | TBD | selection_required | Castellated-edge or through-hole header termination acceptable; confirm voltage dimensions mounting and genuine Sensirion device
BAT-001 | power | Protected 3.7 V 18650 Li-ion cell 2600-3500 mAh | 1 | each | TBD | TBD | Protected cylindrical 18650 cell | TBD | TBD | 8.00 | CAD | TBD | TBD | candidate | Brainstorm price estimate; use a qualified protected cell and confirm peak current and dimensions
BAT-HOLDER-001 | mechanical | Single-cell 18650 holder with leads | 1 | each | TBD | TBD | Single-cell wired 18650 holder | TBD | TBD | TBD | CAD | TBD | TBD | candidate | Confirm polarity lead gauge and enclosure fit
GLAND-001 | mechanical | PG7 cable gland sized for probe cable | 1 | each | TBD | TBD | PG7 threaded cable gland | TBD | TBD | TBD | CAD | TBD | TBD | candidate | Measure the actual cable diameter before selection
FASTENER-001 | mechanical | M2 fastener set for controller stack | 1 | set | TBD | TBD | M2 metric fastener set | TBD | TBD | TBD | CAD | TBD | TBD | candidate | Set quantity and length after enclosure layout
ENCLOSURE-001 | mechanical | Printed PETG or ASA enclosure | 1 | each | Open Plant Pulse | TBD | Custom 3D-printed multipart housing | self-fabricated | TBD | TBD | CAD | TBD | TBD | design_required | Publish editable CAD material mass and print settings

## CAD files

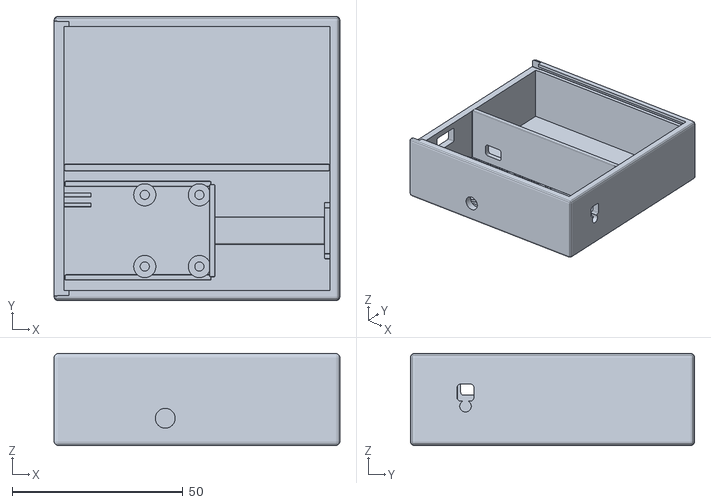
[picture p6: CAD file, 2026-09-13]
sensor/hardware/enclosure/stl/air-node-case-base-v1.stl
83.8 x 83.3 x 27.0

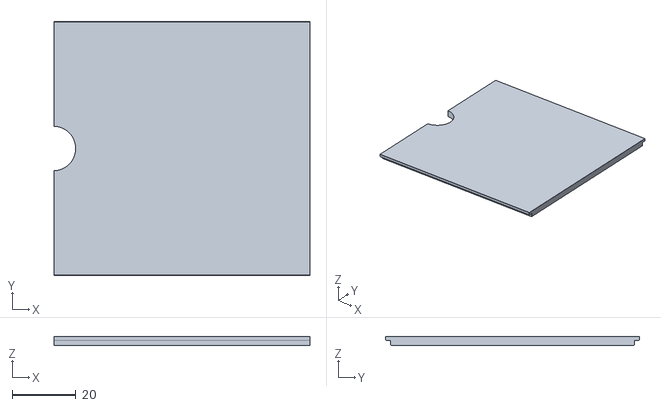
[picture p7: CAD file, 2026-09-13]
sensor/hardware/enclosure/stl/air-node-case-lid-v1.stl
80.4 x 79.7 x 2.80

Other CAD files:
sensor/hardware/enclosure/source/air-node-case-v1.blend
sensor/hardware/enclosure/source/pi_case.blend

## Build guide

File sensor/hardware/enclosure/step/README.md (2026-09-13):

# STEP exports

Store revisioned `.step` or `.stp` exports here for CAD interchange and assembly
fit checks. Every export must correspond to a committed model under `../source/`.

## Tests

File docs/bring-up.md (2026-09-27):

# Prototype bring-up checklist

Record measurements, manual links, board revisions, and photos in a GitHub issue
or dated test report. Do not mark an item complete from a product listing alone.
Use the [sensor power-management design](power-management.md) when verifying
deep sleep, switched rails, wake timing, and current consumption.

## Before power

- [ ] Exact controller, expansion board, probe, and SHT45 revisions recorded.
- [x] NPKPHCTH-S supply range and wire functions confirmed from its manual/label
	(CWT "NPK type" manual V1.4: DC 4.5-30 V; brown +, black -, yellow/green A, blue B).
- [ ] RS485 board input/output ranges and 12 V current limit confirmed.
- [ ] Power-enable signal, polarity, and default state verified.
- [x] UART pins verified as D4/GPIO6 TX, D5/GPIO7 RX and D2/GPIO4 DE by working
	Modbus reads through the XIAO RS485 board (2026-09-26).
- [ ] Battery holder polarity and protected-cell requirement verified.
- [ ] All power rails checked for shorts with no battery or USB attached.

## SHT45 bench test

- [ ] Exact bare-sensor or breakout pinout and supply range confirmed.
- [x] I2C address `0x44` is detected on D1/GPIO3 SDA and D3/GPIO5 SCL, shared with
	the INA219 at `0x40`. D4/D5 belong to the RS485 board (2026-09-26).
- [ ] Pull-up configuration and bus voltage verified with the actual assembly.
- [x] CRC-checked temperature and humidity reads complete without errors
	(firmware 0.13.2 and 0.13.3 serial logs, 2026-09-26).
- [ ] Readings are compared with a reference instrument after thermal settling.
- [ ] Self-heating and nearby electronics heat are checked in final placement.
- [ ] Ventilation protects the sensing opening from splashes and condensation.

## USB-only firmware

- [x] ESP-IDF target builds without warnings.
- [x] Board boots and emits the startup log over USB (needs a data cable; a
	charge-only cable powers the board but no port appears).
- [ ] Reset and bootloader recovery procedure tested.

## Bench supply and probe

- [ ] Probe first powered from a current-limited bench supply.
- [x] Probe tested with the battery fitted. On USB alone the XIAO's charger
	cannot supply it, and moisture, temperature and pH read 0 (2026-09-26).
- [ ] Idle, startup, and measurement currents recorded.
- [x] Modbus baud, parity, address, function, registers, and scaling confirmed
	by a raw register dump and a tap-water test (2026-09-26).
- [ ] Moisture, soil temperature, conductivity, pH, N, P, and K registers are
	individually identified rather than inferred from a family/model name.
- [ ] At least 100 reads complete without CRC or timeout errors. Not yet: replies
	occasionally arrive short and are recovered by retries.
- [ ] Open-air/water/reference-medium values are plausible and repeatable. Clean tap
	water: 100 %, 23.8 C, 41 uS/cm, pH 6.8; air: 0 %, 0 uS/cm. No reference medium
	or soil yet.

## Power gating and radio

- [ ] Probe rail is off at reset and during deep sleep.
- [ ] Stabilization delay established by measurement, with margin.
- [ ] Failed reads always remove probe power.
- [ ] One bounded BTHome advertising burst is received and stored by the hub.
- [ ] The hub being absent does not extend the fixed advertisement window.
- [ ] Duplicate callbacks from one burst do not create duplicate stored samples.
- [ ] BTHome payload parses correctly in Home Assistant and the hub.
- [ ] Soil and air temperatures appear as distinct, correctly named values.
- [x] Hub plant name, room, and interval are written during a report and read back.
- [x] Configuration survives reset and appears on the sensor dashboard.
- [x] The next always-awake report window uses the applied interval.
- [ ] Other physical sensors remain independent while configuration is delivered.
- [ ] Deep-sleep and complete-cycle current profiles recorded.

## Enclosure trial

- [ ] Measured 5.0 mm NPKPHCTH-S cable passes through the 5.8 mm circular hole without jacket damage.
- [ ] Cable gland or external clamp provides strain relief; the printed pass-through alone does not retain the cable.
- [ ] No exposed conductor or battery contact can touch condensation.
- [ ] Antenna clearance and orientation are documented.
- [ ] Enclosure temperature and condensation checked in its final location.
- [ ] A service procedure exists for charging, inspection, and battery removal.

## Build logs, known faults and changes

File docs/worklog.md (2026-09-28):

# Open Plant Pulse worklog

## 2026-09-12

### Project context and architecture

- Reviewed the repository structure and documented the intended sensor-to-hub architecture.
- Confirmed the planned sensor lifecycle: wake, sample sensors, advertise BTHome data, and return to deep sleep.
- Kept continuous Wi-Fi and the device web console scoped to powered development and diagnostics because they conflict with the production low-power lifecycle.
- Confirmed the current hardware target is a Seeed Studio XIAO ESP32-C3 revision 0.4 with 4 MB physical flash. The current firmware image and partition configuration still use a 2 MB flash header.

### SHT45 and sensor planning

- Added `docs/sht45-first-node.md` with wiring, command, CRC, integration, and bring-up guidance.
- Selected GPIO6 for SDA and GPIO7 for SCL as candidate SHT45 pins, pending assembled-hardware verification.
- Preserved the distinction between SHT45 ambient temperature and the ESP32-C3 internal die temperature.
- Left RS-485 soil-probe acquisition unimplemented until hardware behavior and register details are validated.

### SHT45 firmware support

- Added a dedicated ESP-IDF SHT45 component using I2C port 0, address `0x44`,
  100 kHz, and configurable GPIO6 SDA/GPIO7 SCL defaults.
- Added the high-precision no-heater `0xFD` measurement, bounded 100 ms bus
  transactions, CRC-8 validation for both words, conversion, and humidity clamping.
- Added a five-second development monitor that invalidates stale data on failures
  and retries an absent sensor without blocking the web console.
- Exposed SHT45 availability, ambient temperature, humidity, and sample age in
  `/status`, added live values to the Sensors view, and added an Overview section
  that appears automatically while the sensor has a valid reading.
- Added host tests for the documented CRC fixture, decoded values, corrupted CRC,
  and 0-100% humidity clamping.

### Mechanical enclosure

- Repaired the Blender MCP environment and established a working Blender automation path.
- Created the parametric enclosure source at `sensor/hardware/enclosure/source/air-node-case-v1.py`.
- Designed an FDM-oriented enclosure for the XIAO ESP32-C3, SHT45, RS-485 carrier, external BLE antenna, dual-18650 holder, sliding lid, USB-C access, sensor exposure, and soil-probe cable routing.
- Generated enclosure exports and iterated toward an approximately 83.8 x 83.3 x 27.0 mm assembly.

### ESP-IDF toolchain and board bring-up

- Installed and validated ESP-IDF v5.5.5 at `~/esp/esp-idf` for the ESP32-C3 target.
- Added canonical firmware tooling:
  - `sensor/firmware/idf-env.sh`
  - `sensor/firmware/build.sh`
  - `sensor/firmware/flush.sh`
- Built and flashed the physical XIAO ESP32-C3 over `/dev/cu.usbmodem14801`.
- Confirmed the Wi-Fi station MAC is `1c:db:d4:f0:ba:e4` and verified its reserved address at `192.168.0.111`.
- Kept local Wi-Fi credentials in ignored `sensor/sdkconfig`; no credential values were added to source or documentation.

### Device web console

- Implemented a native ESP-IDF `esp_http_server` development console.
- Refactored the original diagnostics implementation into the generic `web_ui` module.
- Added station-mode Wi-Fi with DHCP and automatic reconnect.
- Added a bounded 16 KiB in-memory log ring while preserving USB serial logging through `esp_log_set_vprintf()`.
- Added embedded, dependency-free frontend assets:
  - `sensor/firmware/main/web/index.html`
  - `sensor/firmware/main/web/app.css`
  - `sensor/firmware/main/web/app.js`
- Added responsive Overview, Sensors, Logs, and Maintenance views.
- Added `/logs`, `/status`, and a no-content `/favicon.ico` route.
- Added `docs/proposals/sensor-web-ui.md` with the staged web-console architecture and delivery plan.

### Chip temperature

- Integrated the ESP32-C3 internal temperature sensor using `esp_driver_tsens`.
- Added `chip_temperature_c` to `/status`, returning `null` when unavailable.
- Added a Chip temperature card to Overview labeled `Internal die, not ambient`.
- Initialized the temperature peripheral before starting Wi-Fi so `/status` cannot race an uninitialized sensor handle.
- Verified a live reading around 51.9-53.9 C while Wi-Fi was active. This is a device-health measurement, not room temperature.

### Persistent UI configuration

- Added a versioned UI configuration module:
  - `sensor/firmware/main/web_ui_config.c`
  - `sensor/firmware/main/web_ui_config.h`
- Stored the bounded JSON configuration in the dedicated `web_ui` NVS namespace so it survives resets, power loss, and normal firmware flashing.
- Added configuration endpoints:
  - `GET /api/v1/config/ui`
  - `PUT /api/v1/config/ui`
  - `POST /api/v1/config/ui/reset`
- Added strict validation for schema version, known fields, theme values, card IDs, duplicate cards, card spans, body size, and the requirement that at least one card remain visible.
- Added customization controls for:
  - Dark, light, or system color mode.
  - Green, blue, or amber accent.
  - Comfortable or compact density.
  - Overview card order, visibility, and one- or two-column width.
  - JSON import, export, and reset to defaults.
- Added immediate browser previews with debounced automatic persistence after each control change.
- Documented storage behavior and the API in `docs/firmware.md`.

### Defects found and corrected

- Corrected embedded asset linker symbols after ESP-IDF stripped the `web/` path from generated symbol names.
- Added missing component dependencies discovered during builds, including `esp_timer` and `esp_driver_tsens`.
- Fixed a lifetime bug where parsed cJSON string pointers outlived their JSON document by copying values into owned fixed-size fields.
- Fixed an HTTP worker stack overflow during configuration writes by moving bounded JSON buffers to the heap and increasing the server task stack to 6 KiB.
- Adjusted temperature initialization ordering to remove a potential early-request race.
- Avoided using `path` as a zsh variable because it aliases the shell's `PATH` array.

### Validation completed

- Built the final firmware successfully with `sensor/firmware/build.sh`.
- Flashed the physical board successfully with `sensor/firmware/flush.sh --no-monitor`.
- Final firmware size was approximately `0xe12a0` bytes, leaving about 12% of the current 1 MiB application partition free.
- Verified live `/status` responses, including connection state, uptime, free heap, MAC, and chip temperature.
- Verified default configuration reads, valid writes, strict `400` rejection of malformed/unknown configuration, and reset behavior.
- Verified custom configuration survived reflashing without NVS erase.
- Exercised the actual Maintenance controls to save and reset a custom layout.
- Verified desktop rendering at 1440 x 900 and mobile rendering at 390 x 844 without horizontal overflow.
- Left the physical device running the default dark, green, comfortable layout at `http://192.168.0.111/`.

### Device restart

- Added `POST /api/v1/restart` with a bounded, strictly validated
  `{"confirm":"restart"}` JSON request.
- Scheduled restart through a 750 ms one-shot timer so the HTTP client receives
  `202 Accepted` before `esp_restart()` runs.
- Added a confirmed Maintenance action with disabled, restarting, reconnecting,
  success, and failure states.
- Verified invalid and duplicate requests are rejected, the physical device
  restarts and reconnects, and its NVS-backed UI configuration is preserved.

### Firmware versioning

- Established `sensor/version.txt` as the authoritative Semantic Versioning
  source, beginning with firmware `0.1.0`.
- Exposed the compiled ESP-IDF application version as `firmware_version` in
  `/status` and included it in the startup log.
- Added the live firmware version to the web console browser title and header
  subtitle, including on narrow screens.

### RTC clock synchronization

- Added plausible-date validation for 2024 through 2099 and bounded SNTP startup
  after DHCP when the clock is invalid or due for drift correction.
- Added configurable 15-second attempts, 15-minute failure retries, 12-hour
  correction cadence, and clock-jump logging without rewriting prior samples.
- Added retained SHT45 sample sequence numbers, monotonic offsets, and nullable
  acquisition-time UTC values so unsynchronized samples remain orderable.
- Added UTC date/time and RTC status cards to the Overview ESP32-C3 section, with
  automatic migration of existing dashboard schema-v1 layouts.

### Inferred power source

- Added USB Serial/JTAG host detection to `/status` as `usb_connected` and
  `power_source`.
- Added a configurable Overview Power card showing `USB` or `Battery (inferred)`,
  with automatic migration of existing schema-v5 dashboard layouts.
- Documented that USB wins when both sources are present and that the battery state
  assumes USB chargers and power banks are not used.
- Built and flashed firmware 0.1.5, then validated the USB state and schema-v5 to
  schema-v6 migration on the connected ESP32-C3.

### Configurable status polling

- Added a Maintenance setting for `/status` refresh intervals from one second to
  one hour, including Off while retaining the initial page-load request.
- Persisted the interval in the NVS-backed UI configuration and migrated existing
  schema-v6 configurations to the prior two-second default.
- Bumped firmware to 0.1.6, passed the repository checks and ESP-IDF build, flashed
  the connected ESP32-C3, and verified 0.1.6 in its serial startup log.
- Verified through the live device APIs that the retained configuration migrated
  to schema v7 with the two-second interval and seven-card layout.

### Absolute humidity dashboard metric

- Added browser-side absolute humidity derivation from SHT45 temperature and
  relative humidity readings using the Magnus approximation.
- Added the AH value to the Overview ambient-sensor grid and documented that it
  is derived rather than supplied by the sensor protocol.
- Bumped firmware to 0.1.7, passed the repository checks and ESP-IDF build,
  flashed the connected ESP32-C3, and verified 0.1.7 and the AH card through the
  live device APIs.

### Remaining work

- Validate every status-polling choice and Off behavior in a browser, including
  continued clock rendering while automatic `/status` polling is disabled.
- Validate SHT45 readings and failure recovery on the connected physical board.
- Validate the inferred battery transition while the node remains battery-powered
  after its USB data connection is removed.
- Validate the purchased RS-485 soil probe register map and implement bounded acquisition.
- Add battery voltage, charge state, Wi-Fi signal, reset reason, and stale-reading health indicators.
- Complete versioned status/log APIs and log controls described in the web UI proposal.
- Design authentication or a physical-presence policy before exposing sensitive maintenance operations.
- Revisit the flash header and partition table before adding OTA or larger persistent assets.
- Return the production firmware to a BLE/deep-sleep lifecycle after bench diagnostics are complete.

## 2026-09-13

### Hub BTHome phases 1–2 validation

- Installed the declared hub development dependencies in an isolated `.venv` and
  confirmed the dependency set is consistent with `pip check`.
- Exercised CoreBluetooth discovery on macOS and observed 40 BLE devices without a
  permission or adapter error.
- Started the production `BleakSubscriber` with its BTHome `0xFCD2` filter and
  observed `scanner.status` remain `scanning` with no error.
- Observed no BTHome broadcaster, so `last_receive_at` remained null; physical
  BTHome reception, multi-sensor radio behavior, and Linux BlueZ permissions remain
  unvalidated.
- Completed phases 1–2 using captured evidence: repeated replay across restart and
  the production scanner callback path keep three sensor identities isolated,
  suppress duplicate durable samples, preserve partial-source nulls, recover from
  adapter interruption, bound receive diagnostics, and report scanner/database
  health separately.

### Hub phase 3 and sensor phase 4 start

- Added schema-v3 sensor management fields and browser workflows for the sensor
  inbox, three-sensor fleet monitoring, enrollment, names, rooms, profiles,
  thresholds, archive/restore, and replacement with optional history merge.
- Added sensor-scoped latest-reading, history, and care-log queries, responsive
  navigation/deep links, freshness and unavailable-source states, and same-origin
  checks for browser mutations.
- Bumped sensor firmware to 0.2.0 and added an opt-in air-only production lifecycle:
  fresh SHT45 acquisition, stable BTHome v2 identity, retained packet ID, bounded
  non-connectable advertising, explicit NimBLE shutdown, and timer deep sleep.
- Host sensor tests and 46 hub tests pass. The ESP-IDF 5.5.5 production-mode build
  succeeds. An intermediate 0.2.0 image flashed successfully, after which the USB
  serial device disappeared on sleep before runtime logs could be captured; the
  final radio-shutdown adjustment therefore still needs reflashing. Running-version,
  physical BLE delivery, repeated wake cycles, power measurements, soil-probe
  cleanup, and the 24-hour soak remain unverified.
- Bumped firmware to 0.2.1 and disabled `OPP_PRODUCTION_LIFECYCLE` in the local
  ignored `sensor/sdkconfig` to prepare an always-awake recovery image. Fixed the
  resulting development-build unused-variable warning; canonical checks and the
  ESP-IDF 5.5.5 build pass. The image contains version 0.2.1 and uses 0xf68a0 bytes
  of the 0x100000-byte app partition, leaving 4% free.
- Initial `sensor/firmware/flush.sh --no-monitor` attempts were blocked while no
  ESP32 serial port was present. After USB recovery exposed
  `/dev/cu.usbmodem14801`, the canonical script flashed 0.2.1 successfully and
  verified every written image hash. Releasing BOOT and resetting produced normal
  flash boot; serial logs confirmed running version 0.2.1 and repeated SHT45 samples.
  The HTTP `/status` response confirmed USB power, Wi-Fi at `192.168.0.111`, clock
  synchronization, and a current SHT45 sample. Physical BLE delivery, production
  sleep cycles, power, and soak validation remain unverified.

### Persistent hub-to-sensor configuration

- Bumped firmware to 0.3.0 and added a versioned connected-BLE configuration
  characteristic for plant name, room, and 5-minute-to-24-hour reporting interval.
- Firmware validates and stores accepted configuration in NVS, renders it on the
  sensor dashboard, and applies the interval to future awake reports or deep sleep.
- The hub tracks desired and acknowledged revisions, retries failures after later
  reports, and shows pending/applied/retrying state on sensor detail pages.
- All 60 canonical host checks pass and the ESP-IDF 5.5.5 firmware build succeeds.
  Initial validation was blocked while no serial device was available.

## 2026-09-14

### Firmware 0.3.0 physical configuration validation

- Flashed the always-awake firmware 0.3.0 image through the canonical
  `sensor/firmware/flush.sh` workflow; esptool verified every written image hash.
  Serial boot output confirmed version 0.3.0 and restored NVS revision 1 with plant
  `white bird`, room `living`, and a 30-minute interval.
- Diagnosed `/status` connection resets as an HTTP-task stack-protection fault in the
  enlarged `snprintf` response. Moved the 2,432-byte response buffer to the heap with
  allocation and truncation checks, reran all 60 host checks, rebuilt, and reflashed.
  Five consecutive `/status` requests then returned HTTP 200 without a reset.
- The live `/status` payload reported version 0.3.0, revision 1, `white bird`,
  `living`, 30 minutes, and USB power. Headless Chrome rendered the same revision,
  plant, room, and interval in the board's Overview page.
- Direct CoreBluetooth GATT access from the project `.venv` wrote and read back the
  revision-1 payload exactly. After the final flash/reset, an idempotent read-back
  completed at 08:13:25 UTC, 1,801.8 seconds after the estimated 07:43:24 UTC boot,
  physically confirming the first configured 30-minute report window.
- The direct GATT client consumed that advertising connection, so the concurrently
  running hub did not store a second cadence sample. Multi-sensor physical behavior,
  production deep-sleep operation, measured current/energy, and the 24-hour soak
  remain unverified. `/status` only confirms that the current source is USB; no power
  meter was connected.

## 2026-09-15

### Firmware 0.5.0 manual report acknowledgement

- Added an always-awake diagnostics **Report now** control that interrupts the wait
  for the next configured interval without moving that scheduled deadline.
- Forced reports carry a standard BTHome button-press event and expose a versioned
  request-ID/packet-ID token through the connected-BLE service. The Hub writes that
  exact token back only after durable ingestion and suppresses duplicate GATT attempts
  from repeated callbacks in one advertising burst.
- The sensor dashboard tracks queued, reporting, acknowledged, unacknowledged, and
  failed states and shows both the request and packet IDs. Scheduled and production
  deep-sleep reports remain one-way and do not wait for a Hub.
- Hardware testing at the persisted 3-second interval exposed and fixed starvation
  when the advertising window occupied the complete interval. The scheduler now
  prioritizes a queued manual request as soon as the active window closes without
  moving the periodic deadline.
- The first physical report was durably accepted as packet 18, but macOS retained
  the old GATT service layout and could not discover a newly added characteristic.
  The six-byte token was moved onto the established configuration characteristic,
  with version and payload length distinguishing the two protocols; this avoids a
  service-cache migration requirement.
- All 65 repository checks and JavaScript syntax validation passed. ESP-IDF 5.5.5
  built firmware 0.5.0 with 17% of the app partition free. The canonical flash
  workflow wrote the final image to `/dev/cu.usbmodem14801` and verified every hash.
- Live `/status` confirmed firmware 0.5.0, revision 5, and the persisted 3-second
  interval. Physical request 1 emitted packet 6; the Hub database accepted it at
  `2026-09-15T02:10:44.026289Z`, and firmware recorded the matching acknowledgment
  before report completion. Headless Chrome rendered `Request 1 · packet 6 · report
  stored and Hub acknowledged` from the board's Maintenance page.

## 2026-09-23

### Repository history and hub Wi-Fi onboarding design

- Committed the previously uncommitted body of work in four logical commits:
  the BTHome contract-v2 and connected-BLE protocol definitions, sensor firmware
  0.2.0 through 0.5.1, hub BLE ingestion with sensor management, and the matching
  documentation. All 67 canonical host checks passed before committing.
- Reviewed the existing Wi-Fi path from a customer's perspective. Credentials are
  compile-time `OPP_WIFI_SSID`/`OPP_WIFI_PASSWORD` constants baked into the image;
  no provisioning mechanism of any kind exists, and none is needed on the sensor
  because production telemetry is BLE-only.
- Recorded review findings: changing networks requires a rebuild and reflash, the
  password sits in unencrypted flash, the disconnect handler reconnects immediately
  without backoff and never logs the reason code, the auth threshold silently
  rejects open networks, and no customer-facing setup document exists.
- Added `docs/proposals/sensor-onboarding.md` covering both out-of-box goals for a
  new sensor: registering with the hub and receiving Wi-Fi credentials. The hub is
  the onboarding interface and the sensor raises no access point, because the
  connectable BLE path already exists, needs no router, and costs no flash.
- Recorded the prerequisite found while designing it: the configuration
  characteristic is declared `F_READ | F_WRITE` with no `ble_hs_cfg.sm_*` settings
  anywhere, so the link has no pairing, bonding, or encryption and cannot carry a
  Wi-Fi password until it does.
- Settled the design on two states derived from bond presence, an LE Secure
  Connections handshake whose LTK is derived rather than transmitted, and a
  six-digit factory passkey that provides both man-in-the-middle protection and
  proof of physical possession. The passkey replaces an earlier button-based
  ownership check; no GPIO button is read in firmware, and the BTHome button event
  is produced only by a web-console forced report that a factory-fresh sensor
  cannot reach.
- Recorded the build settings the design depends on: `CONFIG_BT_NIMBLE_NVS_PERSIST`
  is not set, so bonds would live in RAM and be lost on every deep-sleep wake, and
  `CONFIG_BT_NIMBLE_MAX_BONDS` must fall from 3 to 1 for the one-hub rule.
- Recorded that link encryption covers connections only. BTHome advertisements stay
  unencrypted under contract v2, so telemetry privacy needs a separate 16-byte bind
  key; the credential payload must leave room for one to avoid a second migration.
- Reordered the delivery plan to be interface-first: a dedicated hub management
  page and a separate guided onboarding flow, both driven by a simulated sensor
  with no firmware or hardware, produce the state and field contract that the
  later firmware phases implement.
- Recorded a platform constraint found while planning that work: `bleak` cannot
  initiate pairing on macOS, where CoreBluetooth raises `NotImplementedError` and
  the operating system presents its own passkey dialog. The onboarding flow cannot
  own a passkey field there, and macOS and Linux need separate validation.
- Moved Wi-Fi credentials to hub level: one household network entered once on the
  hub settings page, kept in the operating system keychain rather than the readings
  database, with each sensor carrying only an enable flag. Turning that flag off
  stops the sensor's HTTP server and leaves the network, which makes it the control
  for the product's only unauthenticated network surface; it defaults to off. This
  makes Wi-Fi a runtime rather than compile-time decision, and disables SNTP
  synchronisation along with it.
- Measured the advertisement budget for encrypted telemetry against the current
  encoder. Encryption adds 8 bytes into a 24-byte allowance: today's air-only
  payload fits at 17 bytes, but air plus the soil probe reaches 26. Dropping the
  packet-id object when encrypted frees exactly the 2 bytes needed, since the
  encryption counter already provides deduplication and replay protection.
- Settled that there is no Wi-Fi test action. A WPA2 passphrase cannot be checked
  offline, only the four-way handshake proves it, and the hub cannot perform one
  without dropping its own connection; the development hub is on Ethernet with its
  Wi-Fi interface unassociated, so it has no route to try at all. Saving already is
  the test: every sensor whose flag is on tries to join and reports a classified
  result in seconds through the forced-report path. Where the operating system holds
  the password, the settings page offers to fill it in from the keychain or from
  NetworkManager, so it need not be retyped.
- Renamed the primary navigation entry from Fleet to Plants.
- Resequenced the delivery plan around the hardware rather than around features.
  Phases 1 to 5 are written, built, and host-tested with no board and no person;
  phase 6 groups everything that cannot be exercised otherwise, because the macOS
  pairing dialog takes a human, a flash may need the BOOT button, and the
  power-cycle reset ignores `ESP_RST_SW` by design so a software restart cannot
  stand in for it. Nothing in phases 2 to 5 may be called working until phase 6
  says so. The bench sensor's unresponsive SHT45 is a precondition for that session,
  since the first-reading target cannot be measured without a valid sample.
- Made encrypted telemetry the default rather than a setting, which makes contract
  v3 the contract for onboarded sensors and removes the keys page from the
  interface. Each sensor is given its own 16-byte key during onboarding. The hub
  must therefore be able to reveal that key for Home Assistant, must store it
  durably rather than in the keychain because every advertisement needs it, and the
  sensor's counter must stay monotonic across deep sleep or replay protection
  rejects it after every wake.
- Removed the keys and pairing page. Its contents either duplicated the sensors tab,
  belonged in the onboarding flow, or were per-sensor data; the Home Assistant key
  now sits on the sensor it belongs to.
- Required the first reading to arrive during onboarding rather than at the next
  interval, targeting 30 seconds. The hub requests a forced report over the link it
  is already connected on, reusing the existing `opp_force_report_request()` path,
  which is wired only to the web console today. Recorded the failure case seen on
  the bench: a forced report returns `no valid sensor sample` when the SHT45 is not
  responding, so the flow must report that rather than wait.
- Rejected BLE 5 extended advertising as the way out. BTHome records it as
  infeasible because `bleak` lacks support, and `bleak` is the library both this hub
  and Home Assistant depend on, so the sensor would transmit correctly and no
  receiver would hear it.
- Chose power-cycle counting as the physical reset, filtered by `esp_reset_reason()`
  so deep-sleep wakes do not advance it. The RESET button cannot erase anything by
  itself, and GPIO9 is a strapping pin the enclosure does not expose.

## 2026-09-24

### Onboarding phase 1: the hub interface

- Added schema 11: `onboarding_state`, `wifi_enabled`, `wifi_state`, `wifi_failure`,
  and `wifi_address` per sensor, plus one household `wifi_ssid` on the hub. The
  network name is stored without a password, since the database is backed up and
  exported.
- Added store methods for the household network, the per-sensor console switch, the
  reported join result, and the onboarding state. Forgetting the network switches
  every console off; returning a sensor to onboarding clears everything derived from
  its bond. The five join failure reasons are enumerated and enforced, so the browser
  can never be handed a failure it cannot explain.
- Added a Settings page separate from the dashboard, with Sensors and Wi-Fi tabs, and
  a four-step add-a-sensor flow, in its own script. Extended the router from two
  hard-coded pages to a list, and renamed the fleet navigation entry to Plants.
- Added a throwaway preview server so the journey can be walked by a person.
- All 99 canonical host checks pass. Verified in headless Chrome that the settings
  page renders a paired sensor with its address, the Wi-Fi tab loads the saved
  network and hides the sensors panel, and the wizard shows step 1 of 4 with both
  unclaimed sensors listed and Continue disabled until one is chosen.
- Recorded the resulting field and failure contract in the proposal. No firmware
  exists for any of it yet; nothing here has touched hardware.

### Onboarding phase 2 and part of phase 3: firmware

- Bumped firmware to 0.6.0. Configured NimBLE LE Secure Connections with bonding,
  a passkey, and `BLE_HS_IO_DISPLAY_ONLY`, and changed the configuration
  characteristic from plain read/write to requiring an encrypted link. Added a
  six-digit passkey generated on first boot into a `factory` NVS namespace that a
  reset must not clear, refused a second bond so one sensor stays bound to one hub,
  and exposed `onboarding_state` in `/status`.
- Set `CONFIG_BT_NIMBLE_NVS_PERSIST=y` and `CONFIG_BT_NIMBLE_MAX_BONDS=1`. Without
  the first, bonds live in RAM and every deep-sleep wake would lose the hub.
- Added the Wi-Fi credential payload as connected-BLE protocol version 3 on the
  established characteristic, with an NVS store beside the device configuration.
  Host tests cover the round trip, the three payloads staying distinguishable, the
  longest permitted values fitting the budget, and malformed input being refused.
- Replaced the immediate endless Wi-Fi reconnect with a bounded backoff, and
  classified disconnect reasons into the vocabulary the hub and browser share,
  including a twenty-second watchdog for associating without receiving an address.

### Unresolved: the worktree firmware image cannot be verified

- `sensor/firmware/build.sh` exits 0 and the link map lists both `libesp_wifi.a` and
  `libmain.a(web_ui.c.obj)`, but the image it produces is 659,744 bytes where the
  bench 0.5.1 image is 1,277,776, and it contains none of the literals either
  version should carry. A byte search of the bench image finds `wifi` 56 times,
  `sht45_enabled`, and `force_report_state`; the same search of the worktree image
  finds none of them, while finding `0.6.0`, `Open Plant Pulse`, `esp_timer` and
  `nvs`.
- The image was byte-identical in size across three builds, including one after
  deleting `sensor/build` entirely. The two `sdkconfig` files differ only by the two
  intended NimBLE settings.
- The cause is not established. Treat the 0.6.0 firmware as compiling, and nothing
  more: it has not been shown to produce a correct image, it has not been flashed,
  and no pairing, credential, or Wi-Fi behaviour has run on hardware.

## 2026-09-25

### Removed the simulator, and split plant care from sensor configuration

- Deleted `simulator/`, the loopback UDP transport, the simulation fixture and the
  tests that only covered them. The dashboard tests now build their reading in
  place rather than decoding a fixture, so they no longer depend on a transport
  that does not exist. Removed the `simulated-plant-01` row and its 39,017 dummy
  readings from the running hub.
- Moved the raw report log below the configuration and made it a collapsible
  section whose state is remembered per browser.
- Gave each sensor a configuration page at `/sensors/<id>/settings`, reachable
  from the plant page and from each row in hub settings, and took the console
  switch out of that list so it exists in one place. Each page now fetches only
  what it shows.

### Why every report is recorded twice

- The receive log shows two rows per report because the sensor puts its BTHome
  service data in the advertisement and its name in the scan response, and
  CoreBluetooth always active-scans: two packets are received per advertising
  event, 0.1 to 1 ms apart, at different RSSI in 39% of cases. Nothing is stored
  twice; the second row is a diagnostics entry marked duplicate. Not changed.

### Firmware over the air

- Wrote `docs/proposals/firmware-over-the-air.md`: the hub commands over the
  bonded BLE link, the sensor downloads over the household network.
- **Hub.** Images are parsed out of the ESP-IDF application descriptor, so an
  upload that is not an `esp32c3` `open_plant_pulse` image is refused and the
  version is read rather than typed. Images are stored once per digest under
  `~/.open-plant-pulse/firmware/` and served by a separate read-only HTTP server
  on the household network (default port 8081); the management API stays on
  loopback. Settings gained a Firmware tab, and a sensor's configuration page an
  update button with progress.
- **Sensor.** `sensor/partitions.csv` replaces the single-app layout with two
  1600 KiB slots inside the 4 MB the board has always had, keeping `nvs` at its
  offset so the cable flash that introduces it costs nothing. Payload version 7
  starts an update; the sensor streams the image into the spare slot, hashes what
  it wrote, and refuses to make it bootable unless the hash matches.
- **Validated on hardware, 2026-09-25.** 0.12.0 was flashed by cable at
  1,418,944 bytes and came back with its pairing code and its place on the
  network intact. 0.12.1 was then installed **over the air in about fifteen
  seconds**, with the hub showing it downloading and then reporting the new
  version. A reset afterwards booted 0.12.1 from `ota_1`, which is only possible
  if the image had confirmed itself.
- **Rollback, also on hardware.** A deliberately broken 0.12.2 was installed over
  the air, aborted on its first boot, and the bootloader loaded the previous slot:
  `Loaded app from partition at offset 0x1b0000` followed by `Running firmware
  0.12.1 from ota_1`. That image was never committed, and both it and the pre-OTA
  0.11.2 image were deleted from the hub afterwards — installing a single-slot
  image over the air would be a one-way trip back to the cable.
- The bad case exposed a gap: the hub went on saying "restarting" for ever,
  because success is the sensor returning with the new version and nothing
  watched for it never doing so. An update still in flight after five minutes is
  now failed, naming the version the sensor is actually running. Observed
  flipping to `failed` five minutes after the rolled-back install.
- **Not validated.** A sensor that sleeps between reports, more than one sensor
  at a time, and the sensor's refusal of an image whose digest does not match:
  the hub checks its files against the name they are stored under, so it cannot
  serve a mismatching image, and proving that path needs a server built to lie.

## 2026-09-26

### Assembled node: power path and pins

- The node now runs from two parallel 18650 cells charged by an IP2312 USB-C
  module, with an INA219 in series with the pack and an MT3608 boosting the
  system node to 12.4 V for the soil probe. The full table is in
  `sensor/hardware/README.md`.
- **Pin conflict found before any Modbus code ran.** The XIAO RS485 board uses
  D4/D5 for its UART and D2 for driver enable, which is where the SHT45 was.
  The board's receiver drives D5, which would corrupt I2C, and the ESP32-C3 has
  one I2C controller, so the SHT45 moved to D1/D3 beside the INA219. The Kconfig
  defaults now describe this board: I2C on GPIO3/GPIO5, UART on GPIO6/GPIO7, DE
  on GPIO4.
- After the move the SHT45 acknowledged `0x44` but every measurement failed
  its CRC. The cause was a broken wire, not the pins; after repair it read
  cleanly. A broken I2C joint can still acknowledge an address.

### NPKPHCTH-S soil probe support (0.13.0-0.13.3)

- The purchased probe has four wires and five needles; the vendor's readme maps
  it to the "NPK type (5Pin probe)" manual V1.4, whose register map, address 1,
  4800 baud 8N1 and wire colours were used. The table's "function 0x30" is a
  typo for `0x03`; the manual's own examples use `0x03`.
- The manual's worked request and reply, CRCs included, are host test vectors,
  so the parser is checked against the vendor's document rather than itself.
- Firmware reads all seven registers every 10 s, rejects out-of-range values,
  broadcasts moisture, soil temperature and conductivity over BTHome (the hub
  already decodes them), and shows pH and N/P/K on the sensor's own page. The
  BTHome payload is at its 20-byte limit.
- **Occasional short or corrupted replies** (for example a CRC of `ef d5`
  instead of `ef 15`, and one- or two-byte replies) led to three attempts per
  sample in 0.13.2. The console's soil and SHT45 sections now stay visible and
  say `Unavailable` rather than disappearing on a failed sample.
- **Moisture, temperature and pH read exactly 0 in water** while conductivity,
  salinity and TDS were correct. A raw dump through the new debug route
  (`/api/v1/soil/registers`, 0.13.3) showed the firmware reading exactly the
  registers the manual describes, and the probe returning 0 in them. The
  cause: the node was powered from the XIAO's USB cable with no battery, so
  the only source on the system node was the XIAO's small charger, which cannot
  supply the MT3608 and probe. The probe's controller answered, but its
  moisture/temperature sensor and pH electrode did not start. With the battery
  in: moisture 77.6 %, temperature 25.7 C, pH 4.8; fully submerged, moisture
  100.0 %, temperature 25.7 C, EC 97 uS/cm, pH 4.5.
- **pH 4.5 was the container, not the probe.** The same tap water in a clean
  container read pH 6.8 (settling from 7.4), EC 41 uS/cm, 23.8 C and 100 %.
  Residue had made the water acidic and more conductive, and the probe measured
  it correctly. In air: moisture 0 %, EC 0, temperature real (unlike the
  starved probe's 0.0), pH noise.
- N/P/K follow conductivity (1/2/7 at 41 uS/cm) and are estimates, not
  measurements.

### Deployment and reachability

- 0.13.0 was installed over the air through the hub in about 25 s. A
  follow-up install stayed `pending` for more than six minutes: an owned
  sensor on battery advertises only at its reports, so the hub had no window
  to deliver it. The install was cancelled.
- Deployments were then restricted to `flush.sh` over USB-C. Later the same
  day, with development builds always reachable, over-the-air installs were
  allowed again; `AGENTS.md` and `docs/firmware.md` describe both paths. `OPP_ALWAYS_REACHABLE` keeps
  development builds advertising continuously. The development lifecycle
  never deep sleeps; deep sleep exists only in the production lifecycle.
- The first USB attempts failed because the cable was charge-only: the board
  booted and reported `usb_connected: false`, and macOS listed no Espressif
  device. A data cable fixed it.
- 0.13.2, 0.13.3 and 0.13.4 were flashed by `flush.sh`, each with all four
  regions hash-verified, and booted reporting their versions over serial and
  `/status`.
- The Maintenance page's soil-probe row still said "Not implemented" and its
  switch saved a setting nothing read. 0.13.4 wires it like the SHT45 switch;
  verified on the device: off logged "Soil probe sampling disabled" and
  cleared the reading within a second, on resumed sampling immediately.

### Battery monitor (0.14.0-0.14.1)

- The SHT45 driver used to create and delete the I2C bus itself, so switching
  it off would have removed the INA219's bus too. A shared, reference-counted
  bus now serves both on D1/D3.
- The INA219 is read every second with 128-sample averaging. Current is shunt
  voltage over shunt resistance (0.1 ohm assumed), positive into the pack.
  The charge level starts from a resting Li-ion voltage curve, counts charge in
  and out, and is pinned to 100 % at the end of a charge. It survives resets.
- First reading on the device: 4.16 V, +259 mA, "charging", with the C3 on
  USB, so the XIAO's own charger charges the pack through the INA219. This
  confirms the sign of the wiring.
- **0.14.0 declared the pack full 41 s after boot.** Its rule (4.15 V, current
  below C/20 = 250 mA) was met by the XIAO charger's normal current. 0.14.1
  requires 4.18 V below C/20 held for a minute, and discards the retained
  gauge from older firmware. It then read 96.4 % (estimate), +247 mA, 0.7 h to
  full.
- The shunt value (0.1 ohm) and capacity (5000 mAh) are assumptions until
  checked against the parts.

### Probe power switch (0.15.0)

- None of the modules on hand can switch the probe: the RS485 board's 12V
  terminal is an input to its regulator, its 5V OUT is USB power only, and a
  disabled MT3608 still passes battery voltage to the probe. An AO3400
  N-MOSFET now switches the MT3608's ground from D10 (GPIO10), with a
  gate pull-down so the probe starts off.
- Verified: the dashboard switch drives GPIO10; continuity between battery -
  and MT3608 OUT- follows it; the probe answers 2.1 s after power-on.
- **The probe costs 28.5 mA** on battery (30 s averages: on -98.0 and -98.1
  mA, off -69.5 mA). The remaining 69.5 mA is the always-awake development
  firmware: Wi-Fi, continuous BLE advertising, SHT45 and INA219.
- With USB connected the INA219 showed no change at all: the charger holds the
  node at 4.2 V and feeds the loads itself. Loads are measured on battery.
- First pH after power-on is wrong (3.3, then 5.6 at +10 s, versus 6.0-6.8
  after long operation); moisture, temperature and EC are right at once.

### Not validated

- 100 consecutive probe reads without a retry, now that the battery is in.
- Soil readings in real soil against a reference; pH against a buffer.
- The production path's soil read and per-reading probe power cycle, and how
  long pH needs after power-on to be trustworthy.
- The battery monitor on battery alone (discharging and time to empty), a
  charge through the IP2312, a completed charge pinning the level to 100 %,
  and the shunt and capacity values against the actual parts.

## 2026-09-27

### Contract v3 switch-over

- Sensor and hub moved to contract v3 together, with no backward
  compatibility. The hub database was backed up first
  (`~/.open-plant-pulse/hub-backup-2026-09-27-schema16.sqlite3`), and the
  16 to 17 migration was rehearsed on a copy of it: 3,905 readings and 7,945
  advertisements kept, integrity and foreign keys clean, 0.05 s.
- 0.16.0 went over the air from the v2 hub, since a v3 hub cannot reach a v2
  sensor, then the hub restarted on v3 and migrated the live database.
- **First v3 reports exposed two gaps.** Report 1 reached the hub as its
  supplementary packet only: the hub held one packet per device while waiting
  for its name, and the supplementary overwrote the main. A Bleak scan from
  the Mac showed both packets arriving, which placed the fault in the hub. And
  forced reports ended unacknowledged: the hub acknowledges once both packets
  are stored, which lands after the sensor's three-second window.
- Fixed by holding up to eight packets per unnamed device, and by accepting the
  acknowledgement for 60 seconds after the window (0.16.1).
- 0.16.1 was installed over the air through the v3 hub in 25 seconds, and the
  hub saw the sensor return on the new version. Forced report 3 was
  acknowledged six seconds after it started. Its reading has soil, air, pH
  5.6, N/P/K 1/3/7, battery 91 % at 4.112 V, and the sensor's timestamp.
  Report IDs continued across the update (1, 2, 3).

- **An interval change waited out the old interval.** The report loop fixed
  its next deadline once per report, so when the hub changed the interval from
  30 minutes to 5 seconds two minutes after a report, the sensor kept waiting
  for the 30-minute deadline while its own page updated every 10 seconds.
  0.16.2 re-reads the interval on every pass, counting from the last report;
  reports then reached the hub every few seconds.
- At a 5-second interval the loss is visible: of reports 4-12, the hub got both
  packets of 4, 10, 11 and 12, only the supplementary of 5, 6 and 9, and
  nothing of 7 and 8. Each report is on air for one window before the next
  replaces it, the Mac's scanning misses some advertisements, and the hub's own
  connections pause advertising. At a 30-minute interval each report is
  repeated for the whole interval.

### Durable delivery (0.17.0, schema 18)

- Contract v3 step 2 landed: an owned sensor queues each report in NVS and
  advertises the oldest until the hub's five-byte acknowledgement names it.
  Every report now carries a supplementary packet so the hub knows when it is
  complete; forced reports are ordinary reports. The migration to schema 18 was
  rehearsed on a copy of the live database (4,024 readings, 118 supplements,
  8,064 advertisements kept) and the live one backed up first
  (`hub-backup-2026-09-27-schema17.sqlite3`).
- On the device at the same 5-second interval that lost about half the reports
  before: reports 164-171 all reached the hub, each acknowledged within
  seconds, none missing. Throughput is one acknowledgement per 6-8 seconds, so
  at 5 seconds a backlog grew by about three reports a minute; at a minute or
  more the queue stays empty.

### Freshness at a 5-second interval (0.18.0-0.18.1)

- One report per connection could not keep up with a report every 5 seconds,
  and advertising the oldest report meant the hub page showed data minutes old.
  The sensor now advertises its newest report, keeps to a fixed schedule with
  advertising windows ending before a report is due, and the hub drains the
  queue in pages over one connection on a gap or every 30 seconds; its latest
  reading is the highest complete report ID.
- Measured over 90 seconds at 250 ms advertising (0.18.0): exactly one report
  every 5 s, queue 0-3, measurement to hub latest median 3.4 s; but 7 of 18
  reports never showed as latest, because the Mac heard only 0-4 advertisements
  of each packet. A Bleak scan showed the main and supplementary packets
  received about equally often, so packet size was not the cause.
- At 50 ms advertising in the always-awake firmware (0.18.1): 17 of 19 reports
  shown, page updates median 5.0 s apart, measurement to hub latest median
  1.8 s (max 4.6 s), queue 0-5. The two not shown were stored complete by the
  drain. Production keeps 250 ms.

- Drains that are due now wait until the report just heard is complete, so
  the connection falls in the quiet part of the cycle instead of across a
  fresh report (hub only). Over three minutes, 16.5 hours into the sensor's
  uptime at a 5-second interval: 34 of 36 reports shown as latest, page updates
  median 5.0 s apart, measurement to hub latest median 3.0 s (max 5.2 s),
  queue 0-6. The uptime and report IDs (about 11,900 reports) agree: no
  restarts, and the queue never filled.

### Battery charging on the hub (0.19.0, schema 19)

- The supplementary packet's battery group gained BTHome's charging object
  `0x16`; the hub stores it (migration 19, rehearsed on a copy of the live
  database: 18,299 readings, 14,393 supplements and 22,339 advertisements kept)
  and draws a bolt over its battery glyph.
- A switch-over hazard: queued reports of the previous format would be refused
  by the new hub forever and block the sensor's queue. The queue now records its
  packet format, and firmware with another format discards old ones at boot.
- On the device, charging from the XIAO's USB: the hub's latest reading was
  report 14510, 100 % at 4.208 V, charging true; queue empty afterwards. The
  user confirmed the bolt on the hub page, gone when the charger was unplugged
  and back when it was plugged in again.

### Packet names, protocol tables and CI (schema 20)

- The two packets of a report are now packet 1 and packet 2 throughout the
  documentation, firmware, hub and fixtures (migration 20 renamed the table to
  `report_packet2`). The protocol README gained byte tables for both packets,
  the device-info byte's bits, and how a report reaches the hub page.
- CI on Ubuntu failed in the Wi-Fi credential codec, which used POSIX `strnlen`
  under strict C11; it now bounds strings with `memchr`, reproduced and checked
  on Debian in the vmpi VM before pushing.

### Soil in the pot

- The probe went into the bird of paradise's pot at 17:04 local time. All
  earlier readings were bench tests in water and air and were deleted from the
  hub (18,393 readings with their packets and advertisements, and 16 care
  events; backup `~/.open-plant-pulse/backups/hub-before-test-data-cleanup-2026-09-27.sqlite3`).
- The probe read EC 0 in dry soil (about 17 %). A half-cup watering at the
  probe took moisture to 100 % and EC to 133 µS/cm, settling near 28 % and
  about 50: EC 0 meant dry soil, not a fault.
- The hub now estimates pore-water EC from bulk EC, moisture and soil
  temperature (Hilhorst, with Topp for the bulk permittivity), and shows the
  last valid estimate while the soil is too dry to measure (below 20 %). Estimates
  so far are about 150-390 µS/cm against the 500-1500 target: nutrients low.
- The strelitzia's moisture targets were lowered for an airy mix: water below
  18 %, comfortable 18-55 %, after watering 35-55 %.
  `docs/proposals/learned-watering-thresholds.md` proposes learning them per pot.

### Hub page

- The probe's bulk EC moved under soil chemistry; a 30-day soil moisture chart
  sits beside soil temperature; the whole comfortable cycle is the green zone;
  the air temperature and humidity cards gave way to ideal-range bands and a
  status line on the air history charts.
- The page rebuilt its lists and charts and rewrote every value every second:
  1,150 DOM changes in ten seconds with unchanged data. Writes now skip
  unchanged values and lists and charts rebuild only when their data changes:
  0 changes on every page with unchanged data, and one update per affected
  element when a report arrives (measured in headless Chrome).

### Pot response

- A pot counted as settled after three readings within 1.5 points, whatever
  their spacing: at a 30-second interval that is one minute, and this watering
  was called settled at 44 % after 10 minutes. It now needs 20 minutes within
  1.5 points; replayed on the same readings it settles at 27.7 % after 46
  minutes, keeping 13 % of the rise. That entry, from a partial test watering,
  and a watering recommendation raised under the old 35 % refill line were
  deleted (backups in `~/.open-plant-pulse/backups/`).

### Hub address and remote access

- The hub listened on 127.0.0.1:8080, so `imacpro.local`, which resolved to
  IPv6 as well, was refused whenever a browser tried IPv6 first. It now listens
  on port 80 on `::`, taking IPv4 and IPv6, and answers only requests from the
  computer it runs on (403 otherwise, `--allow-network` to open it): macOS lets
  an ordinary user bind port 80 only on the wildcard address. Checked from the
  Mac on localhost, 127.0.0.1, ::1, the LAN address and the .local name over
  both families. The refusal was not checked from a second computer: the Lima
  VM's traffic reaches the Mac through a host-side relay and arrives as local.
- The LaunchAgent and app bundle are now in `deploy/launchd/`, with an install
  script; the installed launcher was re-signed and the scanner came back
  `scanning`.
- The Mac was renamed `imac`, and the page is served to the owner's devices at
  `https://imac.<tailnet>.ts.net` through Tailscale Serve (tailnet only),
  checked from the Mac and opened on the owner's iPhone.

### Grow light control

- Read the Grow Light Control technical specification extracted from the
  glowlight project and wrote `docs/proposals/grow-light-control.md`. Decisions:
  lights are managed in Settings › Lights, a light belongs to at most one plant,
  the GL1C's colour is a setting on the light, and a plant's first schedule is
  08:00 to 21:30, the window gl1cd runs today.
- Added schema version 21 (`lights`, `plant_lights`, `plant_light_schedules`,
  `light_events`) and the `lighting` package: a driver interface, the
  `neewer-gl1c` and `wemo-switch` drivers ported from `gl1cd.py`, and a light
  service that runs gl1cd's schedule, watchdog and manual-override rules per
  light, each light on its own worker.
- Added `/api/light-drivers`, `/api/lights` and `/api/sensors/<id>/lighting`,
  the Settings › Lights tab, a Lighting card on the plant page, and a Lighting
  section on the plant's configuration page. `sh scripts/check.sh` passes, 301
  tests, 49 of them new.
- Walked the pages in Chrome against the preview hub with a simulated light:
  added it, switched it on by hand, gave it to a plant with the 08:00 to 21:30
  window at 23:29, and the scheduler switched it off on its next pass, logged as
  a confirmed schedule action; no console errors.

### Grow light cut-over and hardware checks

- Backed up the database as `hub-backup-2026-09-27-schema20.sqlite3` (integrity
  ok), stopped and disabled `com.keefo.gl1cd` and `com.keefo.gl1cmenu` (left
  installed), and reinstalled the hub service from the `keefo/grow_light_support`
  worktree. The database migrated to schema 21; the scanner kept `scanning`.
- The hub then got `[Errno 65] No route to host` for every LAN address while
  `curl` from Terminal reached the Wemo. One-shot launchd probes showed why:
  Apple's `python3` (exempt) reached it and the venv's Homebrew Python did not,
  with no prompt and no entry in Local Network settings. Local network privacy
  cannot attribute a connection to an app whose main executable is a shell
  script. The bundle now has a compiled launcher (`deploy/launchd/launcher.c`)
  that runs `Contents/Resources/hub.sh` as its child, and `Info.plist` carries
  `NSLocalNetworkUsageDescription`. A throwaway bundle built the same way
  prompted, and once allowed connected; the hub then appeared in System
  Settings › Privacy & Security › Local Network, switched on by the owner.
- Added both lights: Neewer GL1C (beacon MAC `f3:6c:5e:cf:f6:9e`) and Sansi 36W
  (Wemo at 192.168.0.208). Both came online reporting off, as gl1cd had left them.
- Manual on, then off, for each light: all four confirmed by the device (GL1C
  0x07 report, Wemo read-back), 0.17 s and 0.38 s for the two ons. The owner saw
  both lights come on.
- Linked both lights to white bird with a 23:40 to 23:44 window at 23:41: both
  switched on at 23:41:37 and 23:41:38, confirmed. Restarting the hub at 23:42
  left both on with no new command. Both were switched off by hand from the page
  at 23:43, so the 23:44 edge found them off and sent nothing.
- White bird's window is now 08:00 to 21:30, enabled; both lights off.

### Not validated

- The GL1C's colour: its own display was not read after a hub power-on, so
  brightness 100 % and 4200 K are unconfirmed on the light.
- A window edge that switches a light off (the only off edge found the lights
  already off), and the first real 08:00 on.
- Recovery after the hub computer's network drops for a minute.
- Moving the service back to the main checkout: it needs this branch merged,
  or the schema-20 backup restored, since the main code refuses schema 21.
- A full queue on hardware, and a report surviving a power cut while queued.
- The hub refusing a request from another computer on the household network.
- `deploy/launchd/install.sh` run for real; it was rendered to a scratch
  directory and matched the installed files, but not used to install.
- Home Assistant decoding the battery objects from the supplementary packet.
- The flash progress bar against a real USB flash.

### Probe power between samples (0.20.0)

- The always-awake path powered the probe on before its first reading and left
  it on for ever after; only switching sampling off at the console brought it
  down. It now powers on, warms up, reads, and powers off around each sample, as
  the production path has always done, so the probe's 28.5 mA is drawn for about
  2.3 s of every 10 rather than continuously.
- A power lock holds the supply for a whole on-read-off sequence, because the
  console's debug register read and the monitor task can now want the probe at
  the same time. That read powers the probe up for the question and puts it back
  afterwards, rather than failing because sampling happened to be between
  samples.
- `sensor/sdkconfig` on this Mac was stale from 0.12.1 and predated every soil
  probe option, with SHT45 still on GPIO6/7 where the RS485 pins now live. It
  was regenerated from `sdkconfig.defaults` keeping only the Wi-Fi credentials,
  which is why this build also moves SHT45 to GPIO3/5.
- Built at 1,470,816 bytes. **Not flashed and not measured**: no board is on USB,
  and the sensor's console is off so it cannot be reached over the air either.
  The saving, and what the first pH after each power-on is worth, are both
  unverified.

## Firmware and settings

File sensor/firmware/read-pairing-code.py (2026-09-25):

"""Read a freshly flashed sensor's pairing code from its boot log.

A sensor's pairing code proves that whoever adds it is holding it, so it must be
readable without the hub and without a network. A sold sensor carries it on a
label. A self-built one has no label, and cannot show it on its own console
either: that console needs Wi-Fi, Wi-Fi credentials arrive over the paired link,
and the link needs the code. The one moment the code is reachable is at the
bench, over USB, which is where this runs.

Resets the board and prints the code. Nothing is transmitted anywhere.
"""

import sys
import time

try:
    import serial
except ImportError:  # pragma: no cover - environment guidance, not logic
    sys.exit("pyserial is required: use the ESP-IDF python, or pip install pyserial")

PATTERN = "Pairing code for this device's label:"
BOOT_SECONDS = 20


def main() -> int:
    if len(sys.argv) < 2:
        return int(bool(sys.exit("usage: read-pairing-code.py /dev/cu.usbmodemXXXX")))
    port_name = sys.argv[1]

    with serial.Serial(port_name, 115200, timeout=1) as port:
        port.setDTR(False)
        port.setRTS(True)
        time.sleep(0.2)
        port.setRTS(False)  # release reset so the board boots

        deadline = time.time() + BOOT_SECONDS
        while time.time() < deadline:
            line = port.readline().decode("utf-8", "replace").strip()
            if PATTERN in line:
                code = line.rsplit(":", 1)[1].strip()
                print()
                print(f"    Pairing code: {code}")
                print()
                print("    Write this on the sensor before closing its case.")
                print("    Adding a sensor does not ask for it: one that belongs to")
                print("    nobody is claimed by the first hub that asks. The code")
                print("    is kept for a future recovery path and is unused today.")
                print()
                return 0

    print(
        "No pairing code seen. The board may not have restarted; unplug it,\n"
        "plug it back in, and run this again.",
        file=sys.stderr,
    )
    return 1


if __name__ == "__main__":
    raise SystemExit(main())

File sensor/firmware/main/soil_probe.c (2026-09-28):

#include "soil_probe.h"

#include <string.h>

#include "driver/gpio.h"
#include "driver/uart.h"
#include "esp_attr.h"
#include "esp_log.h"
#include "esp_timer.h"
#include "freertos/FreeRTOS.h"
#include "freertos/semphr.h"
#include "freertos/task.h"
#include "sdkconfig.h"

#if CONFIG_OPP_SOIL_PROBE_ENABLED

#define SOIL_PROBE_UART UART_NUM_1
/* Must exceed the 128-byte hardware FIFO for the driver to accept it. */
#define SOIL_PROBE_RX_BUFFER_SIZE 256
/* The manual gives no reply latency; at 4800 baud the 19-byte reply alone
 * takes 40 ms, so half a second is generous without stalling the task. */
#define SOIL_PROBE_RESPONSE_TIMEOUT_MS 500
#define SOIL_PROBE_READ_SLICE_MS 20
#define SOIL_PROBE_REQUEST_SIZE 8
/* Replies on the prototype sometimes lose their last bits or bytes. A retry
 * costs 100 ms; a sample lost costs a whole interval. */
#define SOIL_PROBE_ATTEMPTS 3
#define SOIL_PROBE_RETRY_DELAY_MS 100
#define SOIL_PROBE_TASK_STACK_SIZE 3072
#define SOIL_PROBE_TASK_PRIORITY 5

static const char *TAG = "soil_probe";
static bool uart_installed;
static bool power_configured;
/* Without a power switch the probe is always on. */
static bool probe_powered = CONFIG_OPP_SOIL_PROBE_POWER_GPIO < 0;
static int64_t powered_at_us;
static bool answer_time_logged;

static portMUX_TYPE sample_lock = portMUX_INITIALIZER_UNLOCKED;
static TaskHandle_t monitor_task;
static opp_soil_probe_sample_record_t latest_sample;
static int64_t latest_sample_time_us;
static bool latest_sample_valid;
static bool monitor_enabled;
static esp_err_t last_error = ESP_ERR_INVALID_STATE;
static RTC_DATA_ATTR uint64_t sample_sequence;

/* One request/reply exchange at a time: the monitor task and a debug read from
 * the web console share the half-duplex bus, and interleaved requests would
 * garble both replies. */
static SemaphoreHandle_t bus_lock(void)
{
    static StaticSemaphore_t storage;
    static SemaphoreHandle_t lock;
    static portMUX_TYPE create_lock = portMUX_INITIALIZER_UNLOCKED;
    portENTER_CRITICAL(&create_lock);
    if (lock == NULL) {
        lock = xSemaphoreCreateMutexStatic(&storage);
    }
    portEXIT_CRITICAL(&create_lock);
    return lock;
}

/* Held for a whole power-on, read, power-off sequence.
 *
 * The bus lock covers one exchange; this covers the supply. Without it a debug
 * read from the console could power the probe up while the monitor task was
 * switching it off around its own read, and one of them would be talking to an
 * unpowered probe. */
static SemaphoreHandle_t power_lock(void)
{
    static StaticSemaphore_t storage;
    static SemaphoreHandle_t lock;
    static portMUX_TYPE create_lock = portMUX_INITIALIZER_UNLOCKED;
    portENTER_CRITICAL(&create_lock);
    if (lock == NULL) {
        lock = xSemaphoreCreateMutexStatic(&storage);
    }
    portEXIT_CRITICAL(&create_lock);
    return lock;
}

/* Put the probe back to sleep: the UART first, so no pin is left driving a
 * transceiver that is about to lose its supply. */
static void release_probe(void)
{
    const esp_err_t uart_error = opp_soil_probe_deinit();
    if (uart_error != ESP_OK) {
        ESP_LOGW(TAG, "Could not release the RS485 UART: %s", esp_err_to_name(uart_error));
    }
    const esp_err_t power_error = opp_soil_probe_set_power(false);
    if (power_error != ESP_OK) {
        ESP_LOGW(TAG, "Could not switch probe power off: %s", esp_err_to_name(power_error));
    }
}

static esp_err_t install_uart(void)
{
    if (uart_installed) {
        return ESP_OK;
    }

    const uart_config_t config = {
        .baud_rate = CONFIG_OPP_SOIL_PROBE_BAUD_RATE,
        .data_bits = UART_DATA_8_BITS,
        .parity = UART_PARITY_DISABLE,
        .stop_bits = UART_STOP_BITS_1,
        .flow_ctrl = UART_HW_FLOWCTRL_DISABLE,
        .source_clk = UART_SCLK_DEFAULT,
    };
    esp_err_t error = uart_driver_install(SOIL_PROBE_UART, SOIL_PROBE_RX_BUFFER_SIZE,
                                          0, 0, NULL, 0);
    if (error != ESP_OK) {
        return error;
    }
    error = uart_param_config(SOIL_PROBE_UART, &config);
    /* The transceiver's driver-enable goes on the UART's RTS output, which the
     * hardware raises for exactly as long as a request is on the wire. Timing
     * it from software would risk clipping the last byte or the first byte of
     * the reply. */
    if (error == ESP_OK) {
        error = uart_set_pin(SOIL_PROBE_UART, CONFIG_OPP_SOIL_PROBE_TX_GPIO,
                             CONFIG_OPP_SOIL_PROBE_RX_GPIO, CONFIG_OPP_SOIL_PROBE_DE_GPIO,
                             UART_PIN_NO_CHANGE);
    }
    if (error == ESP_OK) {
        error = uart_set_mode(SOIL_PROBE_UART, UART_MODE_RS485_HALF_DUPLEX);
    }
    if (error != ESP_OK) {
        uart_driver_delete(SOIL_PROBE_UART);
        return error;
    }
    uart_installed = true;
    return ESP_OK;
}

esp_err_t opp_soil_probe_init(void)
{
    xSemaphoreTake(bus_lock(), portMAX_DELAY);
    const esp_err_t error = install_uart();
    xSemaphoreGive(bus_lock());
    return error;
}

esp_err_t opp_soil_probe_set_power(bool on)
{
#if CONFIG_OPP_SOIL_PROBE_POWER_GPIO >= 0
    if (!power_configured) {
        const gpio_config_t config = {
            .pin_bit_mask = 1ULL << CONFIG_OPP_SOIL_PROBE_POWER_GPIO,
            .mode = GPIO_MODE_OUTPUT,
            .pull_up_en = GPIO_PULLUP_DISABLE,
            .pull_down_en = GPIO_PULLDOWN_DISABLE,
            .intr_type = GPIO_INTR_DISABLE,
        };
        /* Low before it becomes an output, so configuring it cannot pulse
         * the probe on. */
        gpio_set_level(CONFIG_OPP_SOIL_PROBE_POWER_GPIO, 0);
        esp_err_t error = gpio_config(&config);
        if (error != ESP_OK) {
            return error;
        }
        power_configured = true;
    }
    if (on == probe_powered) {
        return ESP_OK;
    }
    esp_err_t error = gpio_set_level(CONFIG_OPP_SOIL_PROBE_POWER_GPIO, on ? 1 : 0);
    if (error != ESP_OK) {
        return error;
    }
    probe_powered = on;
    ESP_LOGI(TAG, "Probe power %s (GPIO%d)", on ? "on" : "off",
             CONFIG_OPP_SOIL_PROBE_POWER_GPIO);
    if (on) {
        powered_at_us = esp_timer_get_time();
        answer_time_logged = false;
        vTaskDelay(pdMS_TO_TICKS(CONFIG_OPP_SOIL_PROBE_WARMUP_MS));
    }
    return ESP_OK;
#else
    (void)on;
    return ESP_OK;
#endif
}

bool opp_soil_probe_is_powered(void)
{
    return probe_powered;
}

esp_err_t opp_soil_probe_deinit(void)
{
    if (!uart_installed) {
        return ESP_OK;
    }
    esp_err_t error = uart_driver_delete(SOIL_PROBE_UART);
    if (error == ESP_OK) {
        uart_installed = false;
    }
    return error;
}
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

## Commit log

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2026-09-24 Add BTHome contract v2 and connected-BLE protocol definitions
    Document the sensor-v2 BTHome service-data contract, the device
    configuration characteristic, and the forced-report acknowledgement
    token. Add the contract-v2 replay fixture used by hub and sensor tests.
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2026-09-24 Add hub BLE ingestion, durable storage, and sensor management
    Add continuous BTHome 0xFCD2 subscription with bleak, a deterministic
    replay adapter sharing the same ingestion interface, explicit SQLite
    migrations, transactional readings with bounded receive diagnostics,
    bounded backoff after adapter loss, and independent scanner, database,
    and last-receive health reporting.
    Add the schema-v3 sensor management surface: the unclaimed-sensor
    inbox, fleet monitoring, enrollment, names, rooms, profiles,
    thresholds, archive/restore, and replacement with optional history
    merge. Add sensor-scoped latest-reading, history, and care-log queries
    with freshness and unavailable-source states, and same-ori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
2026-09-24 Add hub Wi-Fi onboarding design and delivery plan
    Introduce the Raspberry Pi hub appliance as a packaging target and
    define how a household customer gets a headless hub onto home Wi-Fi.
    Recommend a two-tier design: Raspberry Pi Imager pre-configuration for
    the common first install, and a hub-owned NetworkManager setup hotspot
    with a captive portal for pre-imaged appliances, router changes, and
    recovery. Sensor nodes stay BLE-only.
    Cover the single-radio state machine, the nmcli wrapper boundary, setup
    endpoints, honest join-failure classification, setup-hotspot security,
    Wi-Fi and BLE coexistence on the shared radio, mDNS discovery, a
    four-phase delivery plan, and a validation strategy. No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
2026-09-24 Retarget Wi-Fi onboarding design at the ESP32-C3 sensor
    Replace the Raspberry Pi hub appliance proposal with a shorter design
    for the sensor node itself, which is the device the customer actually
    onboards.
    Move credentials from Kconfig constants into NVS, serve a setup access
    point and captive portal from the existing esp_http_server and embedded
    asset pipeline, and classify disconnect reasons instead of retrying
    silently. Record the flash-budget risk against the nearly full app
    partition. Nothing is implemented.
2026-09-24 Redesign sensor onboarding around hub-driven BLE enrolment
    Cover both out-of-box goals for a new sensor: registering with the hub
    and receiving Wi-Fi credentials. Make the hub the onboarding interface
    and drop the sensor access point and captive portal. The connectable
    BLE path already exists, needs no router, and costs no flash on a
    nearly full app partition.
    Record the prerequisite this exposed: the configuration characteristic
    is F_READ | F_WRITE with no ble_hs_cfg.sm_* settings anywhere, so the
    link has no pairing, bonding, or encryption and cannot carry a Wi-Fi
    password until it does.
    Record that no GPIO button is read in firmware, so the proposed
    ownership check needs new firmware wo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
2026-09-24 Settle the onboarding handshake, states, and reset design
    Define two sensor states derived from bond presence, so the state
    cannot disagree with reality, and make a reset the only way back to
    onboarding. That is what makes one sensor, one hub true.
    Use LE Secure Connections rather than a designed key exchange: both
    sides derive the LTK by ECDH and it is never transmitted. Add a
    six-digit factory passkey that gives both man-in-the-middle protection
    and proof of physical possession, replacing the earlier button-based
    ownership check that a factory-fresh sensor cannot perform.
    Record what encryption does not cover: advertisements are broadcast, so
    telemetry stays unencrypted under contract v2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
2026-09-24 Reorder the onboarding plan to be interface-first
    Make phase 1 a dedicated hub management page and a separate guided
    onboarding flow, both driven end to end by a simulated sensor with no
    firmware change and no hardware. The customer journey is the riskiest
    part of the design and the cheapest to change, the hub iterates in
    seconds where firmware iterates in flash cycles, and the resulting
    states, fields, and failure reasons become the contract the firmware
    phases implement.
    Scope the management page to what the hub can actually hold: the bonded
    sensor, forget and transfer, write-only Wi-Fi credentials, and later a
    bind key. The hub never sees the LTK and must not store the passkey.
    Record t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
2026-09-24 Encrypt telemetry by default and deliver the first reading during onboarding
    Make the bind key unconditional rather than a setting: privacy every
    household should have is not a toggle. Each sensor is given its own
    16-byte key at onboarding, which makes contract v3 the contract for
    onboarded sensors.
    Record what follows. Home Assistant can no longer read a sensor unless
    the hub can reveal its key, so the key belongs on that sensor's own
    settings. The hub must store it durably rather than in the keychain,
    because decoding every advertisement needs it, which puts keys in
    database backups. The counter must stay monotonic across deep sleep or
    replay protection rejects the sensor after every wake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
2026-09-24 Add a network check to household Wi-Fi settings
    Report whether the network is in range, whether it is 2.4 GHz, and what
    security it uses, from the hub's own scan.
    Do not test the password: the hub joining the network to try it would
    disconnect the hub, and only a sensor joining proves a password. The
    check earns its place by catching the two failures customers blame on
    the sensor instead, a mistyped or hidden name and a 5 GHz-only network
    the ESP32-C3 can never join.
    Record its limits: reading SSIDs needs Location permission on macOS,
    and a hub with no Wi-Fi adapter must say it could not look rather than
    report a failure.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
2026-09-24 Resequence the plan around the hardware
    Order the phases by what needs a person rather than by feature. Phases
    1 to 5 are written, built, and host-tested with no board and no
    operator; phase 6 groups everything that cannot be exercised any other
    way, so it is one hands-on session rather than five.
    Three things force that grouping: the macOS pairing dialog belongs to
    the operating system and no automation reaches it, a flash may need the
    BOOT button, and the power-cycle reset ignores ESP_RST_SW by design so
    a software restart cannot stand in for pulling the plug.
    State plainly that nothing in phases 2 to 5 may be described as working
    until phase 6 says so, and record the bench sensor's unre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
2026-09-24 Add onboarding state and household network to the hub
    Give every sensor an onboarding state, a console switch, and a join
    result, and give the hub one household network name. Schema 11.
    The fields are the contract the firmware must later satisfy, so they
    are deliberate: onboarding_state derives the sensor's two states,
    wifi_enabled is the switch, and wifi_state plus wifi_failure carry a
    classified answer rather than silence. Every failure reason a sensor
    can give is enumerated and enforced, so the browser can never have to
    say only that it did not work.
    Store the network name without a password: the database is backed up
    and exported, and the password belongs in the operating system
    keycha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
2026-09-24 Add the settings page and the guided add-a-sensor flow
    Give the hub a Settings page of its own, separate from the monitoring
    dashboard, with a Sensors tab carrying each sensor's console switch and
    a Wi-Fi tab carrying the one household network. Add a four-step flow
    for adding a sensor: find, pair, name, done.
    Keep the flow in its own script rather than extending the dashboard's,
    because it is a distinct surface, and extend the router from its two
    hard-coded pages to a list. Rename the fleet navigation entry to
    Plants, which is what a household is actually looking at.
    Say what a sensor is doing rather than whether it worked: every
    classified join failure has wording, a console that has been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
2026-09-24 Classify Wi-Fi failures and back off between retries
    Say why a join failed instead of retrying in silence. The disconnect
    reason becomes one of the vocabulary the hub and browser already share,
    and a sensor that associates but receives no address within twenty
    seconds reports that too, which no disconnect reason ever covers.
    Replace the immediate, endless reconnect with a bounded exponential
    backoff. The old loop burned power and filled the log while telling
    nobody what was wrong.
    Note the one limit: a 5 GHz-only network is indistinguishable from an
    absent one on this radio, since the ESP32-C3 never sees it and both
    arrive as WIFI_REASON_NO_AP_FOUND.
    Document the Wi-Fi credential payload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
2026-09-24 Store delivered Wi-Fi credentials, and record a build anomaly
    Add the NVS store for the household network, beside the device
    configuration and cleared by the same reset, with the password
    write-only: never returned on a read, never in a status response, never
    logged, and deliberately absent even from the log line that reports a
    successful load.
    Record an unresolved problem honestly rather than claiming a working
    build. sensor/firmware/build.sh exits 0 and the link map lists both
    libesp_wifi.a and libmain.a(web_ui.c.obj), but the image is 659,744
    bytes where the bench 0.5.1 image is 1,277,776, and contains none of
    the literals either version should carry. A byte search of the bench
    image fin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
2026-09-24 Make forgetting a sensor actually release it
    Forgetting only flipped the onboarding flag and left the sensor
    enrolled, so it stayed in the settings list and on the plants page with
    its label changed and nothing else. The bond is what makes a sensor
    belong to a hub, so releasing it must return the sensor to the
    unclaimed list, exactly where a factory-fresh one starts.
    Keep the readings. Adding the sensor again then continues one history
    rather than starting a second; deleting a sensor outright remains a
    separate, destructive action.
    Call the badge "Not paired" rather than "Onboarding", which read as a
    process the sensor was undergoing rather than a state it was in, and
    ask for confirmation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
2026-09-25 Offer only pairable sensors, and show the real scan state
    The simulator was offered as something to add. It reaches the hub over
    UDP and has no radio, so there is nothing to pair with; the same is true
    of a sensor last heard from days ago, which is not in the room. Both
    would have failed at the pairing step with no way for anyone to tell
    why, so step one now offers only BTHome sensors seen in the last five
    minutes.
    That makes an empty list the normal case while waiting, so say what the
    hub is doing. The indicator reports the scanner's actual status rather
    than animating regardless: it can say the scanner is not running, and
    shows its last error when there is one. An indicator that always sp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
2026-09-25 Advertise an onboarding beacon when there is nothing to measure
    A sensor was only discoverable while it had a valid reading, so a board
    with no probe attached, or a broken one, never advertised at all. It was
    invisible at the one moment it most needs to be reachable: before anyone
    owns it. An unbonded sensor now sends an identity-only beacon instead,
    is adopted normally, and reports its sensor fault afterwards, which is
    where a fault belongs. Once bonded, silence is the honest signal and the
    hub's staleness handling reports it.
    The beacon is device info and a packet ID, nothing more. The hub accepts
    that exact shape and records presence without inventing a reading, so
    history never holds ro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
2026-09-25 Make the scanning list live, and always re-deliver config on adoption
    Switching a sensor off left it in the list. The list polls every second,
    so the staleness was not in the page: presence is inferred from the last
    advertisement, and a sensor beaconing on a thirty-minute reporting
    interval cannot be told apart from one that has been switched off. A
    short window alone would have made a live sensor flicker out between
    beacons, so the cadence had to change with it.
    An unclaimed sensor now beacons every ten seconds rather than on its
    reporting interval. Somebody is looking for it in a list that has to feel
    live, the sensor is powered and attended during setup, and the cadence
    ends the moment i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
2026-09-25 Bring the scanning list inside a ten-second reaction time
    Unplugging a sensor took about thirty seconds to show, and plugging it
    back in took about as long again. Both had the same cause: the list can
    only react as fast as the sensor announces itself, and it announced
    itself every ten seconds after waiting a full interval to start.
    An unclaimed sensor now beacons every three seconds, which is also the
    advertising window, so it effectively announces itself continuously, and
    it sends one immediately at start-up instead of after a first interval.
    The candidate window falls to ten seconds, three missed beacons. Plugging
    in or pulling out is now reflected inside the agreed ceiling in both
    direct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
2026-09-25 Report the pairing code at the bench, where it can be read
    Showing the code on the sensor's own console only works on a bench
    build. That console needs Wi-Fi, the credentials arrive over the paired
    link, and the link needs the code, so on a real device the page does not
    exist yet at the moment somebody needs to read it. The card stays, since
    it is useful on a bench image and correctly disappears once paired, but
    it does not answer the question.
    A sold sensor carries the code on a label. A self-built one has no
    label, and the only moment the code is reachable without the hub and
    without a network is at the bench over USB. The flash script now resets
    the board, reads the code from its boot lo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
    [read-pairing-code.py]
2026-09-25 Claim sensors without a code, and defend ownership instead
    Adopting a sensor no longer asks for anything. Pairing drops to Just
    Works: the link is still encrypted and the long term key is still
    derived rather than transmitted, and what is given up is protection
    against someone sitting in the middle of that one exchange.
    What is protected instead is ownership. A sensor that belongs to nobody
    is claimed by the first hub that asks; a sensor that is already claimed
    refuses every other hub, checked against stored keys the moment a
    central connects rather than after encryption, because there is no
    longer a code to prove who is connecting. Re-pairing is allowed only
    from the hub that already owns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
    [read-pairing-code.py]
2026-09-25 Keep the last onboarding step working after it is reached
    Claiming finishes in a moment, but the console still has to join a
    network and the first reading still has to arrive, and both take longer
    than a person takes to read the page. The summary was frozen at the
    instant Finish was pressed, so it asserted things that had not happened:
    it showed the console as pending forever, and it called a reading stored
    days earlier the first one from this setup.
    Each row now re-reads the live sensor and says where it has actually got
    to. The console row moves through waiting, joined with its address, or
    the specific reason it failed. The reading row waits until a reading
    arrives after setup finished, t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
2026-09-25 Offer the whole compass for a room's windows
    Four directions could not describe most rooms. North-east and north are
    not the same morning, a corner room faces more than one way, and a
    windowless room is a real answer rather than a missing one. Eight
    compass points, several directions, and no windows.
    Widening a CHECK means rebuilding the table, and sensors holds a foreign
    key into rooms that a single-transaction migration cannot safely drop
    and recreate; the attempt failed on exactly that. Renaming the column
    and adding a replacement keeps the constraint enforced in the database
    without touching the key, at the cost of leaving the old column behind
    unused.
    Verified by migrating a populated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
2026-09-25 Say "nothing to measure" instead of going quiet
    Onboarding hung on "Waiting for the first reading" and would have waited
    for ever. The sensor has no probe attached, so it has no reading to
    send, and once it belonged to a hub it stopped advertising altogether.
    Silence cannot be told apart from a flat battery or a sensor carried out
    of range, so the hub had nothing to say and said nothing.
    A sensor with no valid sample now beacons rather than skipping its
    report. The beacon carries no measurement, which is the truth, and it
    lets the hub distinguish a sensor that is present and measuring nothing
    from one that is not there at all.
    Adoption also triggers a report immediately instead of at the n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
2026-09-25 Treat reporting in as the end of setup, not a measurement
    The last step waited for a probe reading, which was my assumption rather
    than the goal. Setup proves the sensor reached the hub: that it is
    claimed, in range, and being heard. A sensor announcing itself with
    nothing to measure has done all of that.
    The row now completes when the sensor reports after setup, showing its
    measurements when it has them and saying its probe is not reading when
    it has none. A missing probe is a note on a finished setup rather than a
    setup that never finishes. Hearing nothing at all is still a failure,
    because that one means setup did not work.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
2026-09-25 Put the console switch on the sensor page, drop three unasked-for controls
    The console switch belongs with a sensor's other settings as well as on
    the Settings list, because the sensor page is where somebody is standing
    when they want to reach that sensor's own diagnostics. It is disabled,
    with a reason, until a household network exists.
    Remove replace, archive and delete from the same page. None were asked
    for; all three arrived with earlier fleet-management work and sat
    together as destructive-looking buttons with nothing to say which to
    use when. Releasing a sensor now covers what people actually do, and it
    explains itself.
    The store keeps all three, so any of them can come back as a de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
2026-09-25 Make the console control a switch, and stop it overstating itself
    Replace the bare checkbox with a pill switch, built on a real checkbox
    so keyboard use and screen readers are unchanged and only the appearance
    differs. It respects reduced motion and shows a focus ring.
    The label claimed "Web console on" the moment the switch was clicked,
    when all that had happened was a row changing in the hub. Only the
    sensor can say its console is on, and it says so by reporting the
    address it joined at; until then this is a request and now says so.
    That wording will stay at "Requested" for every sensor until the hub can
    actually deliver credentials, which is not built. Saying so is the
    point: the switch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
2026-09-25 Reach a sensor in seconds while it is powered or being worked on
    A configuration change took up to a reporting interval to arrive,
    because a hub can only reach a sensor while it is advertising and an
    owned sensor advertised every half hour. Two changes close that, and one
    bug found on the way mattered more than either.
    Reachability is now separate from reporting. Between reports a sensor
    re-advertises its last payload unchanged: the hub sees the same packet
    ID, stores no reading, and can connect. Mains power removes the reason
    to be frugal, so a plugged-in sensor does this continuously; on battery
    it does it for two minutes after any hub connection, because somebody
    who changes one setting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
2026-09-25 Link to a reachable console, and show the delivered revision
    Offer the sensor's own console as a link, but only once the sensor has
    reported that it joined and given an address. Before that there is
    nothing at the other end of it.
    Show which configuration revision the sensor has acknowledged, beside
    its identity, and flash it when it moves. Configuration is delivered
    rather than saved, so the number that matters is the one the sensor
    confirmed, and seeing it change is how somebody watching knows a setting
    actually travelled rather than inferring it from a status line that
    reads the same either way. The flash is skipped under reduced motion,
    where the colour alone carries it.
    Co-Authored-By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
2026-09-25 Remove the simulation clock and time scaling
    The analogue clock and its speed multiplier existed to make a simulator
    running at many times real time legible. Readings now come from a
    physical sensor at its own pace, so the clock showed real time badly and
    the multiplier stayed at one: two pieces of machinery inferring a time
    base that no longer needs inferring.
    Gone entirely: the dial and its hands, the scale label, the projection
    that estimated simulated time between samples, and the history read that
    existed only to recover the scale on load. The simulator itself still
    reports a time scale; nothing in the browser derives from it.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
2026-09-27 Read the whole soil probe, the battery and the probe's power, and send it all
    The assembled node gains everything it was wired for, and the hub hears all of it.
    - Soil probe: the ComWinTop NPKPHCTH-S over Modbus RTU on the XIAO RS485 board
    (TX GPIO6, RX GPIO7, DE GPIO4), all seven registers per the vendor manual,
    whose own request and reply are host test vectors. Retries for the short
    replies the prototype sees, a debug route for raw register dumps, and a
    console switch that really stops sampling.
    - Probe power: an AO3400 in the MT3608's ground, driven from GPIO10, so the
    switch cuts the MT3608 and probe (28.5 mA measured on battery).
    - Battery: INA219 on a shared I2C bus with the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
    [battery_gauge.h]
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2026-09-28 Power the soil probe only while it is being read
    Firmware 0.20.0. The always-awake path powered the probe on before its first
    reading and then left it on, so the 28.5 mA the probe and its boost converter
    draw was spent continuously between samples that are ten seconds apart. It now
    powers on, warms up, reads and powers off around each sample, which is what the
    production path has always done.
    The console's debug register read used to rely on the monitor leaving the
    supply up, and would now fail between samples, so it powers the probe up for
    its question and puts it back afterwards. A power lock holds the supply across
    a whole on-read-off sequence, because those two callers can now want it a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
    [soil_probe.c]
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
